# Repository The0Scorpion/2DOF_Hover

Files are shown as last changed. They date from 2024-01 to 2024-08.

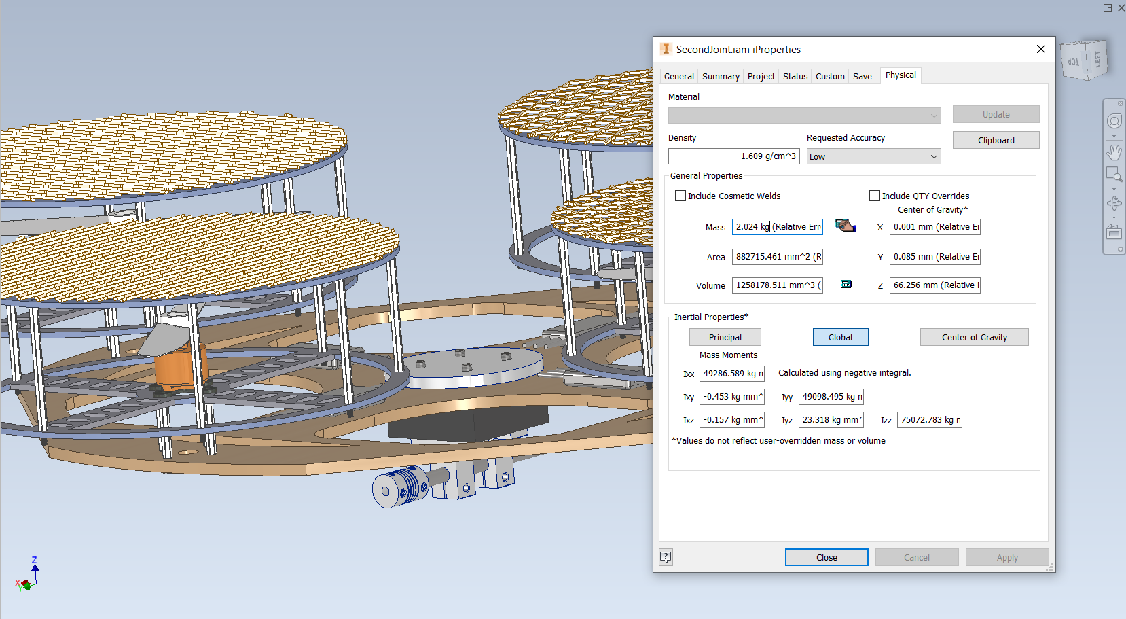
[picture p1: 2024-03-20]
CAD/Inertias/UpperJoint_Inertia_mass.PNG

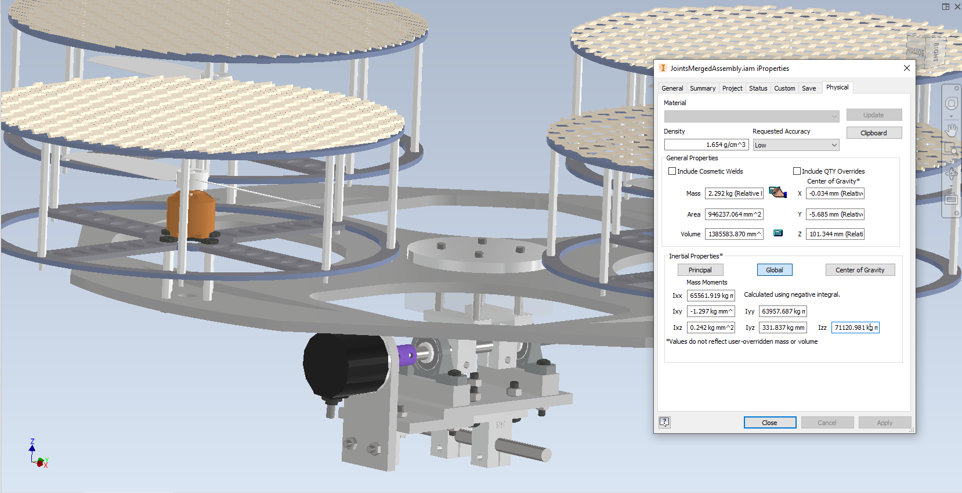
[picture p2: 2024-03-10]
Model/MotorEstimationModel/Inertias/InertiaLowerJoint.PNG

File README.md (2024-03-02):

# 2 DOF Hover
## Objective:
To create a smart lab that is designed to enhance the experince of students and tutors for control theory
## About
This is the full project files containing all of the diffrent source code files and CAD files to build a functional 2 DOF hover 
## Current Progress
We reached a functional state where the experment is working with AWS and Red.js app 
it features the ability to moniter and tune the hover in real-time

This is a Graduation Project Of an Mechatronics Engineering Team From ASU Faculty of engineering.

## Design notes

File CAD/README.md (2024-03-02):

# Mechanical Data
This section contains the CAD files for the mechaincal system
It was built using Autodesk Inventor, this is used to create the non linear model.

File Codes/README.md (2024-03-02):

# Source Codes
This section contains every software file that was used throught the development phase of the project.
### 2DOF_Full_Code
This is the full code of the project, it contains several modules that are working in parellal to maintain the operation of the drone.
### IOT_HubCode
this section is deprecated for the time being 
It will be used as a central hub to be an interface between all of the experiments and the IOT broker.
### IOTHUB_TESTONLY
This code is used for experminting.
Such as determining the paramters and delays.
### MotorResponseGrapher
Code used to determine the motor response curve to input and voltage
You can find the data in the /Data folder.

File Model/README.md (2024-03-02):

# available models for the system
## Non linear model 
The model created using the CAD files that closely relates the real model.
## Roll reduced model
Simplified model to design the controller on.

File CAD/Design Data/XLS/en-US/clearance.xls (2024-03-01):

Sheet: Ansi Unified Screw Threads
I | Sort Order -1
Fastener Type | Size | Shaft Diameters |  |  | Head Dimensions
 |  | Close | Normal | Loose | Diameter | Depth/Angle | Head Type
Flat Head Machine Screw (82) | #0 | 0.0635 | 0.07 | 0.073 | 0.119 | 82 | 2
Flat Head Machine Screw (82) | #1 | 0.076 | 0.081 | 0.089 | 0.146 | 82 | 2
Flat Head Machine Screw (82) | #2 | 0.089 | 0.096 | 0.1065 | 0.172 | 82 | 2
Flat Head Machine Screw (82) | #3 | 0.104 | 0.11 | 0.12 | 0.199 | 82 | 2
Flat Head Machine Screw (82) | #4 | 0.116 | 0.1285 | 0.136 | 0.225 | 82 | 2
Flat Head Machine Screw (82) | #5 | 0.1285 | 0.136 | 0.154 | 0.252 | 82 | 2
Flat Head Machine Screw (82) | #6 | 0.144 | 0.1495 | 0.1695 | 0.279 | 82 | 2
Flat Head Machine Screw (82) | #8 | 0.1695 | 0.177 | 0.1935 | 0.332 | 82 | 2
Flat Head Machine Screw (82) | #10 | 0.196 | 0.201 | 0.221 | 0.385 | 82 | 2
Flat Head Machine Screw (82) | #12 | 0.221 | 0.228 | 0.246 | 0.438 | 82 | 2
Flat Head Machine Screw (82) | 1/4 | 0.257 | 0.266 | 0.2812 | 0.507 | 82 | 2
Flat Head Machine Screw (82) | 5/16 | 0.323 | 0.332 | 0.3437 | 0.635 | 82 | 2
Flat Head Machine Screw (82) | 3/8 | 0.386 | 0.397 | 0.4062 | 0.762 | 82 | 2
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

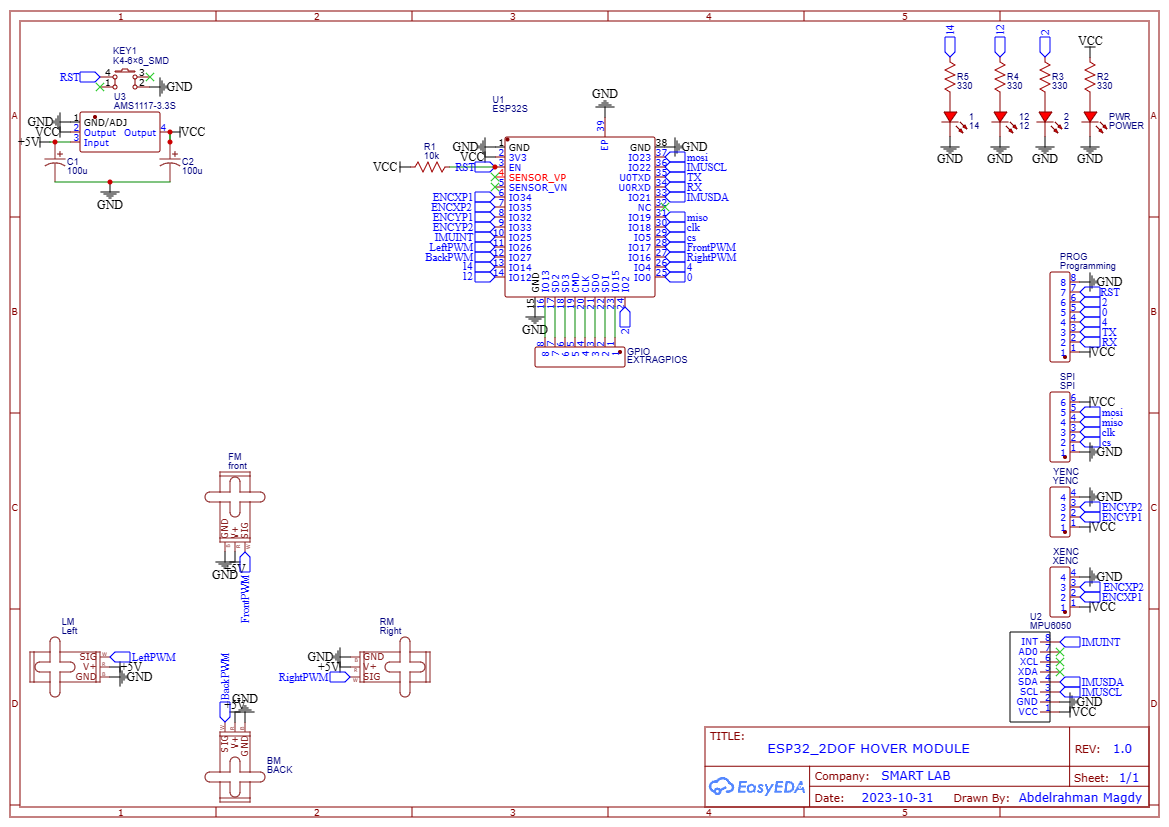
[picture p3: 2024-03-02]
Electric/Schematic_2DOF-Hover.png

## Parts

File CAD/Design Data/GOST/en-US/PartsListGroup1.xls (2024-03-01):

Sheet: Лист 1
Инв. № подл |  |  |  | Подп. и дата | Взам. инв. № | Инв. № дубл. |  |  | Подп. и дата
Формат | Зона | Поз. | Обозначение |  |  |  | Наименование |  |  |  |  |  | Кол. на исполнение
 |  |  |  |  |  |  |  |  |  |  |  | Лит.
 |  |  |  |  |  |  |  |  |  |  |  | Код
 |  |  |  |  |  |  |  | Изм. | Лист | № докум | Подпись |  | Дата
 |  |  |  |  |  |  |  | Разраб.
 |  |  |  |  |  |  |  | Пров.
 |  |  |  |  |  |  |  | Н.контр
 |  |  |  |  |  |  |  | Утв.
 |  |  |  |  |  |  |  |  |  |  |  |  |  | Копировал

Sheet: Лист 2
Инв. № подл |  |  |  | Подп. и дата | Взам. инв. № | Инв. № дубл. |  |  | Подп. и дата
Формат | Зона | Поз. | Обозначение |  |  |  | Наименование |  |  |  |  | Кол. на исполнение
 |  |  |  |  |  |  |  | Изм. | Лист | № докум. | Подп. | Дата
 |  |  |  |  |  |  |  |  |  |  |  |  | Копировал
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

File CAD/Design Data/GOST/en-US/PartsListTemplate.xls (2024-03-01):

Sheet: Лист 1
 | Формат | Зона |  | Поз. |  | Обозначение |  |  |  | Наименование |  |  |  | Кол. | Приме-чание
Подп. и дата
Инв. № дубл.
Взам. инв. №
Подп. и дата
 | Изм. |  | Лист |  | № докум |  | Подпись | Дата
Инв. № подл | Разраб. |  |  |  |  |  |  |  |  |  | Литера |  | Лист |  |  | Листов
 | Пров.
 | Н.контр
 | Утв.
 |  |  |  |  |  |  |  |  | Копировал |  |  | Формат А4

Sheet: Лист 2
 | Формат | Зона |  | Поз. |  | Обозначение |  |  |  | Наименование |  | Кол. | Приме-чание
Подп. и дата
Инв. № дубл.
Взам. инв. №
Подп. и дата
Инв. № подл
 | Изм. |  | Лист |  | № докум. |  | Подп. |  | Дата
 |  |  |  |  |  |  |  | Копировал |  |  | Формат А4
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

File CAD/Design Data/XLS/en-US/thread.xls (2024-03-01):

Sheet: Inch Tapping Threads
I Q X | Inch Tapping Threads |  | Sort Order - 5 |  | External |  |  |  |  |  |  | Internal
 |  |  |  |  |  | Major Dia |  | Pitch Dia |  | Minor Dia |  |  | Minor Dia |  | Pitch Dia |  | Major Dia |  | Tap Drill
Size | Size Suffix | Thread Designation | Custom Thread Designation | TPI | Class | Max | Min | Max | Min | Max | Min | Class | Min | Max | Min | Max | Min | Max | Basic
0.0600 |  | 0-48 | 0-48 | 48 | 2B | 0.0600 | 0.0540 | 0.0480 | 0.0435 | 0.0360 | 0.0330
0.0730 |  | 1-42 | 1-42 | 42 | 2B | 0.0750 | 0.0690 | 0.0620 | 0.0575 | 0.0490 | 0.0460
0.0860 |  | 2-32 | 2-32 | 32 | 2B | 0.0880 | 0.0820 | 0.0760 | 0.0710 | 0.0640 | 0.0600
0.0990 |  | 3-28 | 3-28 | 28 | 2B | 0.1010 | 0.0950 | 0.0880 | 0.0830 | 0.0750 | 0.0710
0.1120 |  | 4-24 | 4-24 | 24 | 2B | 0.1140 | 0.1080 | 0.1000 | 0.0950 | 0.0860 | 0.0820
0.1250 |  | 5-20 | 5-20 | 20 | 2B | 0.1300 | 0.1230 | 0.1120 | 0.1065 | 0.0940 | 0.0900
0.1380 |  | 6-20 | 6-20 | 20 | 2B | 0.1390 | 0.1320 | 0.1215 | 0.1155 | 0.1040 | 0.0990
0.1510 |  | 7-19 | 7-19 | 19 | 2B | 0.1540 | 0.1470 | 0.1345 | 0.1280 | 0.1150 | 0.1090
0.1640 |  | 8-18 | 8-18 | 18 | 2B | 0.1660 | 0.1590 | 0.1440 | 0.1375 | 0.1220 | 0.1160
0.1900 |  | 10-16 | 10-16 | 16 | 2B | 0.1890 | 0.1820 | 0.1650 | 0.1585 | 0.1410 | 0.1350
0.2160 |  | 12-14 | 12-14 | 14 | 2B | 0.2150 | 0.2080 | 0.1895 | 0.1825 | 0.1640 | 0.1570
0.2420 |  | 14-14 | 14-14 | 14 | 2B | 0.2410 | 0.2340 | 0.2130 | 0.2060 | 0.1850 | 0.1780
0.2500 |  | 1/4-14 | 1/4-14 | 14 | 2B | 0.2460 | 0.2370 | 0.2190 | 0.2110 | 0.1920 | 0.1850
0.3125 |  | 5/16-12 | 5/16-12 | 12 | 2B | 0.3150 | 0.3060 | 0.2795 | 0.2710 | 0.2440 | 0.2360
0.3750 |  | 3/8-12 | 3/8-12 | 12 | 2B | 0.3800 | 0.3710 | 0.3445 | 0.3350 | 0.3090 | 0.2990
0.4375 |  | 7/16-10 | 7/16-10 | 10 | 2B | 0.4400 | 0.4290 | 0.3995 | 0.3890 | 0.3590 | 0.3490
0.5000 |  | 1/2-10 | 1/2-10 | 10 | 2B | 0.5040 | 0.4930 | 0.4635 | 0.4530 | 0.4230 | 0.4130

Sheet: Metric Forming Screw Threads
M P X | Metric Forming Screw Threads |  | Sort Order - 6 |  | External |  |  |  |  |  |  | Internal
 |  |  |  |  |  | Major Dia |  | Pitch Dia |  | Minor Dia |  |  | Minor Dia |  | Pitch Dia |  | Major Dia |  | Tap Drill
Size | Size Suffix | Thread Designation | Custom Thread Designation | Pitch | Class | Max | Min | Max | Min | Max | Min | Class | Min | Max | Min | Max | Min | Max | Basic
1.5 |  | 1.5x0.5 | 1.5x0.5 | 0.5 | 6g | 1.520 | 1.380 | 1.215 | 1.110 | 0.910 | 0.840
1.5 |  | ST1.5x0.5 | ST1.5x0.5 | 0.5 | 6g | 1.520 | 1.380 | 1.215 | 1.110 | 0.910 | 0.840
1.9 |  | 1.9x0.6 | 1.9x0.6 | 0.6 | 6g | 1.900 | 1.760 | 1.570 | 1.465 | 1.240 | 1.170
1.9 |  | ST1.9x0.6 | ST1.9x0.6 | 0.6 | 6g | 1.900 | 1.760 | 1.570 | 1.465 | 1.240 | 1.170
2.2 |  | 2.2x0.8 | 2.2x0.8 | 0.8 | 6g | 2.240 | 2.100 | 1.935 | 1.810 | 1.630 | 1.520
2.2 |  | ST2.2x0.8 | ST2.2x0.8 | 0.8 | 6g | 2.240 | 2.100 | 1.935 | 1.810 | 1.630 | 1.520
2.6 |  | 2.6x0.9 | 2.6x0.9 | 0.9 | 6g | 2.570 | 2.430 | 2.235 | 2.115 | 1.900 | 1.800
2.6 |  | ST2.6x0.9 | ST2.6x0.9 | 0.9 | 6g | 2.570 | 2.430 | 2.235 | 2.115 | 1.900 | 1.800
2.9 |  | 2.9x1 | 2.9x1 | 1 | 6g | 2.900 | 2.760 | 2.540 | 2.420 | 2.180 | 2.080
2.9 |  | 2.9x1.1 | 2.9x1.1 | 1.1 | 6g | 2.900 | 2.760 | 2.540 | 2.420 | 2.180 | 2.080
2.9 |  | ST2.9x1.1 | ST2.9x1.1 | 1.1 | 6g | 2.900 | 2.760 | 2.540 | 2.420 | 2.180 | 2.080
2.9 |  | 2.9x1.3 | 2.9x1.3 | 1.3 | 6g | 2.900 | 2.720 | 2.540 | 2.355 | 1.890 | 1.700
2.9 |  | 2.9x1.4 | 2.9x1.4 | 1.4 | 6g | 2.900 | 2.720 | 2.340 | 2.175 | 1.780 | 1.630
3.3 |  | 3.3x1.3 | 3.3x1.3 | 1.3 | 6g | 3.300 | 3.120 | 2.795 | 2.665 | 2.290 | 2.210
3.3 |  | ST3.3x1.3 | ST3.3x1.3 | 1.3 | 6g | 3.300 | 3.120 | 2.795 | 2.665 | 2.290 | 2.210
3.5 |  | 3.5x1.3 | 3.5x1.3 | 1.3 | 6g | 3.530 | 3.350 | 3.085 | 2.930 | 2.640 | 2.510
3.5 |  | ST3.5x1.3 | ST3.5x1.3 | 1.3 | 6g | 3.530 | 3.350 | 3.085 | 2.930 | 2.640 | 2.510
3.5 |  | 3.5x1.6 | 3.5x1.6 | 1.6 | 6g | 3.530 | 3.350 | 2.920 | 2.755 | 2.310 | 2.160
3.5 |  | 3.5x3.2 | 3.5x3.2 | 3.2 | 6g | 3.530 | 3.310 | 2.800 | 2.600 | 2.070 | 1.890
3.9 |  | 3.9x1.3 | 3.9x1.3 | 1.3 | 6g | 3.910 | 3.730 | 3.415 | 3.250 | 2.920 | 2.770
3.9 |  | ST3.9x1.3 | ST3.9x1.3 | 1.3 | 6g | 3.910 | 3.730 | 3.415 | 3.250 | 2.920 | 2.770
3.9 |  | 3.9x1.6 | 3.9x1.6 | 1.6 | 6g | 3.910 | 3.730 | 3.300 | 3.135 | 2.690 | 2.540
3.9 |  | 3.9x3.2 | 3.9x3.2 | 3.2 | 6g | 3.910 | 3.690 | 3.180 | 2.980 | 2.450 | 2.270
4.2 |  | 4.2x1.4 | 4.2x1.4 | 1.4 | 6g | 4.220 | 4.040 | 3.660 | 3.495 | 3.100 | 2.950
4.2 |  | ST4.2x1.4 | ST4.2x1.4 | 1.4 | 6g | 4.220 | 4.040 | 3.660 | 3.495 | 3.100 | 2.950
4.2 |  | 4.2x1.6 | 4.2x1.6 | 1.6 | 6g | 4.220 | 4.040 | 3.610 | 3.445 | 3.000 | 2.850
4.2 |  | 4.2x3.2 | 4.2x3.2 | 3.2 | 6g | 4.220 | 4.000 | 3.380 | 3.180 | 2.540 | 2.360
4.8 |  | 4.8x1.6 | 4.8x1.6 | 1.6 | 6g | 4.800 | 4.620 | 4.190 | 4.025 | 3.580 | 3.430
4.8 |  | ST4.8x1.6 | ST4.8x1.6 | 1.6 | 6g | 4.800 | 4.620 | 4.190 | 4.025 | 3.580 | 3.430
4.8 |  | 4.8x1.8 | 4.8x1.8 | 1.8 | 6g | 4.800 | 4.620 | 4.065 | 3.885 | 3.330 | 3.150
4.8 |  | 4.8x3.2 | 4.8x3.2 | 3.2 | 6g | 4.800 | 4.580 | 3.960 | 3.760 | 3.120 | 2.940
5.5 |  | 5.5x1.8 | 5.5x1.8 | 1.8 | 6g | 5.460 | 5.280 | 4.815 | 4.635 | 4.170 | 3.990
5.5 |  | ST5.5x1.8 | ST5.5x1.8 | 1.8 | 6g | 5.460 | 5.280 | 4.815 | 4.635 | 4.170 | 3.990
6.3 |  | 6.3x1.8 | 6.3x1.8 | 1.8 | 6g | 6.250 | 6.030 | 5.565 | 5.365 | 4.880 | 4.700
6.3 |  | ST6.3x1.8 | ST6.3x1.8 | 1.8 | 6g | 6.250 | 6.030 | 5.565 | 5.365 | 4.880 | 4.700
8.0 |  | 8x2.1 | 8x2.1 | 2.1 | 6g | 8.000 | 7.780 | 7.100 | 6.885 | 6.200 | 5.990
8.0 |  | ST8x2.1 | ST8x2.1 | 2.1 | 6g | 8.000 | 7.780 | 7.100 | 6.885 | 6.200 | 5.990
9.5 |  | 9.5x2.1 | 9.5x2.1 | 2.1 | 6g | 9.650 | 9.430 | 8.750 | 8.510 | 7.850 | 7.590
9.5 |  | ST9.5x2.1 | ST9.5x2.1 | 2.1 | 6g | 9.650 | 9.430 | 8.750 | 8.510 | 7.850 | 7.590

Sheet: ISO Pipe Threads
M Q | ISO Pipe Threads |  | Sort Order - 9 |  | External |  |  |  |  |  |  | Internal
 |  |  |  |  |  | Major Dia |  | Pitch Dia |  | Minor Dia |  |  | Minor Dia |  | Pitch Dia |  | Major Dia |  | Tap Drill | Thread Depth | Thread Runouts
Size | Size Suffix | Thread Designation | Custom Thread Designation | TPI | Class | Max | Min | Max | Min | Max | Min | Class | Min | Max | Min | Max | Min | Max | Basic
7.723 |  | G7.723x0.907 | G 1/16 | 28 | A | 7.723 | 7.509 | 7.142 | 7.035 | 6.561 |  |  | 6.561 | 6.834 | 7.142 | 7.249 | 7.723 |  | 1.5875 | 15.446 | 4.5000
7.723 |  | G7.723x0.907 | G 1/16 | 28 | B | 7.723 | 7.509 | 7.142 | 6.928 | 6.561
9.728 |  | G9.728x0.907 | G 1/8 | 28 | A | 9.728 | 9.514 | 9.147 | 9.040 | 8.566 |  |  | 8.566 | 8.848 | 9.147 | 9.254 | 9.728 |  | 3.1750 | 19.456 | 4.5000
9.728 |  | G9.728x0.907 | G 1/8 | 28 | B | 9.728 | 9.514 | 9.147 | 8.933 | 8.566
13.157 |  | G13.157x1.337 | G 1/4 | 19 | A | 13.157 | 12.907 | 12.301 | 12.176 | 11.445 |  |  | 11.445 | 11.89 | 12.301 | 12.426 | 13.157 |  | 6.3500 | 26.314 | 6.5000
13.157 |  | G13.157x1.337 | G 1/4 | 19 | B | 13.157 | 12.907 | 12.301 | 12.051 | 11.445
16.662 |  | G16.662x1.337 | G 3/8 | 19 | A | 16.662 | 16.412 | 15.806 | 15.681 | 14.950 |  |  | 14.95 | 15.395 | 15.806 | 15.931 | 16.662 |  | 9.5250 | 33.324 | 6.5000
16.662 |  | G16.662x1.337 | G 3/8 | 19 | B | 16.662 | 16.412 | 15.806 | 15.556 | 14.950
20.955 |  | G20.955x1.814 | G 1/2 | 14 | A | 20.955 | 20.671 | 19.793 | 19.651 | 18.631 |  |  | 18.631 | 19.172 | 19.793 | 19.935 | 20.955 |  | 12.7000 | 41.910 | 8.5000
20.955 |  | G20.955x1.814 | G 1/2 | 14 | B | 20.955 | 20.671 | 19.793 | 19.509 | 18.631
22.911 |  | G22.911x1.814 | G 5/8 | 14 | A | 22.911 | 22.627 | 21.749 | 21.607 | 20.587 |  |  | 20.587 | 21.128 | 21.749 | 21.891 | 22.911 |  |  | 45.822 | 8.5000
22.911 |  | G22.911x1.814 | G 5/8 | 14 | B | 22.911 | 22.627 | 21.749 | 21.465 | 20.587
26.441 |  | G26.441x1.814 | G 3/4 | 14 | A | 26.441 | 26.157 | 25.279 | 25.137 | 24.117 |  |  | 24.117 | 24.658 | 25.279 | 25.421 | 26.441 |  | 15.8750 | 52.882 | 8.5000
26.441 |  | G26.441x1.814 | G 3/4 | 14 | B | 26.441 | 26.157 | 25.279 | 24.995 | 24.117
30.201 |  | G30.201x1.814 | G 7/8 | 14 | A | 30.201 | 29.917 | 29.039 | 28.897 | 27.877 |  |  | 27.877 | 28.418 | 29.039 | 29.181 | 30.201 |  | 22.2250 | 60.402 | 8.5000
30.201 |  | G30.201x1.814 | G 7/8 | 14 | B | 30.201 | 29.917 | 29.039 | 28.755 | 27.877
33.249 |  | G33.249x2.309 | G 1 | 11 | A | 33.249 | 32.889 | 31.770 | 31.590 | 30.291 |  |  | 30.291 | 30.931 | 31.77 | 31.95 | 33.249 |  | 25.4000 | 66.498 | 10.0000
33.249 |  | G33.249x2.309 | G 1 | 11 | B | 33.249 | 32.889 | 31.770 | 31.410 | 30.291
37.897 |  | G37.897x2.309 | G 1 1/8 | 11 | A | 37.897 | 37.537 | 36.418 | 36.238 | 34.939 |  |  | 34.939 | 35.579 | 36.418 | 36.598 | 37.897 |  | 28.5750 | 75.794 | 10.0000
37.897 |  | G37.897x2.309 | G 1 1/8 | 11 | B | 37.897 | 37.537 | 36.418 | 36.058 | 34.939
41.910 |  | G41.91x2.309 | G 1 1/4 | 11 | A | 41.910 | 41.550 | 40.431 | 40.251 | 38.952 |  |  | 38.952 | 39.592 | 40.431 | 40.611 | 41.910 |  | 31.7500 | 83.820 | 10.0000
41.910 |  | G41.91x2.309 | G 1 1/4 | 11 | B | 41.910 | 41.550 | 40.431 | 40.071 | 38.952
47.803 |  | G47.803x2.309 | G 1 1/2 | 11 | A | 47.803 | 47.443 | 46.324 | 46.144 | 44.845 |  |  | 44.845 | 45.485 | 46.324 | 46.504 | 47.803 |  | 38.1000 | 95.606 | 10.0000
47.803 |  | G47.803x2.309 | G 1 1/2 | 11 | B | 47.803 | 47.443 | 46.324 | 45.964 | 44.845
53.746 |  | G53.746x2.309 | G 1 3/4 | 11 | A | 53.746 | 53.386 | 52.267 | 52.087 | 50.788 |  |  | 50.788 | 51.428 | 52.267 | 52.447 | 53.746 |  | 44.4500 | 107.492 | 10.0000
53.746 |  | G53.746x2.309 | G 1 3/4 | 11 | B | 53.746 | 53.386 | 52.267 | 51.907 | 50.788
59.614 |  | G59.614x2.309 | G 2 | 11 | A | 59.614 | 59.254 | 58.135 | 57.955 | 56.656 |  |  | 56.656 | 57.296 | 58.135 | 58.315 | 59.614 |  | 50.8000 | 119.228 | 10.0000
59.614 |  | G59.614x2.309 | G 2 | 11 | B | 59.614 | 59.254 | 58.135 | 57.775 | 56.656
65.710 |  | G65.71x2.309 | G 2 1/4 | 11 | A | 65.710 | 65.276 | 64.231 | 64.014 | 62.752 |  |  | 62.752 | 63.392 | 64.231 | 64.448 | 65.710 |  | 57.1500 | 131.420 | 10.0000
65.710 |  | G65.71x2.309 | G 2 1/4 | 11 | B | 65.710 | 65.276 | 64.231 | 63.797 | 62.752
75.184 |  | G75.184x2.309 | G 2 1/2 | 11 | A | 75.184 | 74.750 | 73.705 | 73.488 | 72.226 |  |  | 72.226 | 72.866 | 73.705 | 73.922 | 75.184 |  |  | 150.368 | 10.0000
75.184 |  | G75.184x2.309 | G 2 1/2 | 11 | B | 75.184 | 74.750 | 73.705 | 73.271 | 72.226
81.534 |  | G81.534x2.309 | G 2 3/4 | 11 | A | 81.534 | 81.100 | 80.055 | 79.838 | 78.576 |  |  | 78.576 | 79.216 | 80.055 | 80.272 | 81.534 |  | 69.8500 | 163.068 | 10.0000
81.534 |  | G81.534x2.309 | G 2 3/4 | 11 | B | 81.534 | 81.100 | 80.055 | 79.621 | 78.576
87.884 |  | G87.884x2.309 | G 3 | 11 | A | 87.884 | 87.450 | 86.405 | 86.188 | 84.926 |  |  | 84.926 | 85.566 | 86.405 | 86.622 | 87.884 |  | 76.2000 | 175.768 | 10.0000
87.884 |  | G87.884x2.309 | G 3 | 11 | B | 87.884 | 87.450 | 86.405 | 85.971 | 84.926
100.330 |  | G100.33x2.309 | G 3 1/2 | 11 | A | 100.330 | 99.896 | 98.851 | 98.634 | 97.372 |  |  | 97.372 | 98.012 | 98.851 | 99.068 | 100.330 |  | 88.9000 | 200.660 | 10.0000
100.330 |  | G100.33x2.309 | G 3 1/2 | 11 | B | 100.330 | 99.896 | 98.851 | 98.417 | 97.372
113.030 |  | G113.03x2.309 | G 4 | 11 | A | 113.030 | 112.596 | 111.551 | 111.334 | 110.072 |  |  | 110.072 | 110.712 | 111.551 | 111.768 | 113.030 |  | 101.6000 | 226.060 | 10.0000
113.030 |  | G113.03x2.309 | G 4 | 11 | B | 113.030 | 112.596 | 111.551 | 111.117 | 110.072
125.730 |  | G125.73x2.309 | G 4 1/2 | 11 | A | 125.730 | 125.296 | 124.251 | 124.034 | 122.772 |  |  | 122.772 | 123.412 | 124.251 | 124.468 | 125.730 |  | 114.3000 | 251.460 | 10.0000
125.730 |  | G125.73x2.309 | G 4 1/2 | 11 | B | 125.730 | 125.296 | 124.251 | 123.817 | 122.772
138.430 |  | G138.43x2.309 | G 5 | 11 | A | 138.430 | 137.996 | 136.951 | 136.734 | 135.472 |  |  | 135.472 | 136.112 | 136.951 | 137.168 | 138.430 |  | 127.0000 | 276.860 | 10.0000
138.430 |  | G138.43x2.309 | G 5 | 11 | B | 138.430 | 137.996 | 136.951 | 136.517 | 135.472
151.130 |  | G151.13x2.309 | G 5 1/2 | 11 | A | 151.130 | 150.696 | 149.651 | 149.434 | 148.172 |  |  | 148.172 | 148.812 | 149.651 | 149.868 | 151.130 |  | 139.7000 | 302.260 | 10.0000
151.130 |  | G151.13x2.309 | G 5 1/2 | 11 | B | 151.130 | 150.696 | 149.651 | 149.217 | 148.172
163.830 |  | G163.83x2.309 | G 6 | 11 | A | 163.830 | 163.396 | 162.351 | 162.134 | 160.872 |  |  | 160.872 | 161.512 | 162.351 | 162.568 | 163.830 |  | 152.4000 | 327.660 | 10.0000
163.830 |  | G163.83x2.309 | G 6 | 11 | B | 163.830 | 163.396 | 162.351 | 161.917 | 160.872

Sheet: JIS Pipe Threads
M Q | JIS Pipe Threads |  | Sort Order -12 |  | External |  |  |  |  |  |  | Internal
 |  |  |  |  |  | Major Dia |  | Pitch Dia |  | Minor Dia |  |  | Minor Dia |  | Pitch Dia |  | Major Dia |  | Tap Drill | Thread Depth | Thread Runouts
Size | Size Suffix | Thread Designation | Custom Thread Designation | TPI | Class | Max | Min | Max | Min | Max | Min | Class | Min | Max | Min | Max | Min | Max | Basic |  | Basic
7.723 |  | G7.723x0.907 | G 1/16 | 28 | A | 7.723 | 7.509 | 7.142 | 7.035 | 6.561 |  |  | 6.561 | 6.834 | 7.142 | 7.249 | 7.723 |  | 1.5875 | 15.446 | 4.5000
7.723 |  | G7.723x0.907 | G 1/16 | 28 | B | 7.723 | 7.509 | 7.142 | 6.928 | 6.561
9.728 |  | G9.728x0.907 | G 1/8 | 28 | A | 9.728 | 9.514 | 9.147 | 9.040 | 8.566 |  |  | 8.566 | 8.848 | 9.147 | 9.254 | 9.728 |  | 3.1750 | 19.456 | 4.5000
9.728 |  | G9.728x0.907 | G 1/8 | 28 | B | 9.728 | 9.514 | 9.147 | 8.933 | 8.566
13.157 |  | G13.157x1.337 | G 1/4 | 19 | A | 13.157 | 12.907 | 12.301 | 12.176 | 11.445 |  |  | 11.445 | 11.89 | 12.301 | 12.426 | 13.157 |  | 6.3500 | 26.314 | 6.5000
13.157 |  | G13.157x1.337 | G 1/4 | 19 | B | 13.157 | 12.907 | 12.301 | 12.051 | 11.445
16.662 |  | G16.662x1.337 | G 3/8 | 19 | A | 16.662 | 16.412 | 15.806 | 15.681 | 14.950 |  |  | 14.95 | 15.395 | 15.806 | 15.931 | 16.662 |  | 9.5250 | 33.324 | 6.5000
16.662 |  | G16.662x1.337 | G 3/8 | 19 | B | 16.662 | 16.412 | 15.806 | 15.556 | 14.950
20.955 |  | G20.955x1.814 | G 1/2 | 14 | A | 20.955 | 20.671 | 19.793 | 19.651 | 18.631 |  |  | 18.631 | 19.172 | 19.793 | 19.935 | 20.955 |  | 12.7000 | 41.910 | 8.5000
20.955 |  | G20.955x1.814 | G 1/2 | 14 | B | 20.955 | 20.671 | 19.793 | 19.509 | 18.631
22.911 |  | G22.911x1.814 | G 5/8 | 14 | A | 22.911 | 22.627 | 21.749 | 21.607 | 20.587 |  |  | 20.587 | 21.128 | 21.749 | 21.891 | 22.911 |  |  | 45.822 | 8.5000
22.911 |  | G22.911x1.814 | G 5/8 | 14 | B | 22.911 | 22.627 | 21.749 | 21.465 | 20.587
26.441 |  | G26.441x1.814 | G 3/4 | 14 | A | 26.441 | 26.157 | 25.279 | 25.137 | 24.117 |  |  | 24.117 | 24.658 | 25.279 | 25.421 | 26.441 |  | 15.8750 | 52.882 | 8.5000
26.441 |  | G26.441x1.814 | G 3/4 | 14 | B | 26.441 | 26.157 | 25.279 | 24.995 | 24.117
30.201 |  | G30.201x1.814 | G 7/8 | 14 | A | 30.201 | 29.917 | 29.039 | 28.897 | 27.877 |  |  | 27.877 | 28.418 | 29.039 | 29.181 | 30.201 |  | 22.2250 | 60.402 | 8.8000
30.201 |  | G30.201x1.814 | G 7/8 | 14 | B | 30.201 | 29.917 | 29.039 | 28.755 | 27.877
33.249 |  | G33.249x2.309 | G 1 | 11 | A | 33.249 | 32.889 | 31.770 | 31.590 | 30.291 |  |  | 30.291 | 30.931 | 31.77 | 31.95 | 33.249 |  | 25.4000 | 66.498 | 10.0000
33.249 |  | G33.249x2.309 | G 1 | 11 | B | 33.249 | 32.889 | 31.770 | 31.410 | 30.291
37.897 |  | G37.897x2.309 | G 1 1/8 | 11 | A | 37.897 | 37.537 | 36.418 | 36.238 | 34.939 |  |  | 34.939 | 35.579 | 36.418 | 36.598 | 37.897 |  | 28.5750 | 75.794 | 10.0000
37.897 |  | G37.897x2.309 | G 1 1/8 | 11 | B | 37.897 | 37.537 | 36.418 | 36.058 | 34.939
41.910 |  | G41.91x2.309 | G 1 1/4 | 11 | A | 41.910 | 41.550 | 40.431 | 40.251 | 38.952 |  |  | 38.952 | 39.592 | 40.431 | 40.611 | 41.910 |  | 31.7500 | 83.820 | 10.0000
41.910 |  | G41.91x2.309 | G 1 1/4 | 11 | B | 41.910 | 41.550 | 40.431 | 40.071 | 38.952
47.803 |  | G47.803x2.309 | G 1 1/2 | 11 | A | 47.803 | 47.443 | 46.324 | 46.144 | 44.845 |  |  | 44.845 | 45.485 | 46.324 | 46.504 | 47.803 |  | 38.1000 | 95.606 | 10.0000
47.803 |  | G47.803x2.309 | G 1 1/2 | 11 | B | 47.803 | 47.443 | 46.324 | 45.964 | 44.845
53.746 |  | G53.746x2.309 | G 1 3/4 | 11 | A | 53.746 | 53.386 | 52.267 | 52.087 | 50.788 |  |  | 50.788 | 51.428 | 52.267 | 52.447 | 53.746 |  | 44.4500 | 107.492 | 10.0000
53.746 |  | G53.746x2.309 | G 1 3/4 | 11 | B | 53.746 | 53.386 | 52.267 | 51.907 | 50.788
59.614 |  | G59.614x2.309 | G 2 | 11 | A | 59.614 | 59.254 | 58.135 | 57.955 | 56.656 |  |  | 56.656 | 57.296 | 58.135 | 58.315 | 59.614 |  | 50.8000 | 119.228 | 10.0000
59.614 |  | G59.614x2.309 | G 2 | 11 | B | 59.614 | 59.254 | 58.135 | 57.775 | 56.656
65.710 |  | G65.71x2.309 | G 2 1/4 | 11 | A | 65.710 | 65.276 | 64.231 | 64.014 | 62.752 |  |  | 62.752 | 63.392 | 64.231 | 64.448 | 65.710 |  | 57.1500 | 131.420 | 10.0000
65.710 |  | G65.71x2.309 | G 2 1/4 | 11 | B | 65.710 | 65.276 | 64.231 | 63.797 | 62.752
75.184 |  | G75.184x2.309 | G 2 1/2 | 11 | A | 75.184 | 74.750 | 73.705 | 73.488 | 72.226 |  |  | 72.226 | 72.866 | 73.705 | 73.922 | 75.184 |  |  | 150.368 | 10.0000
75.184 |  | G75.184x2.309 | G 2 1/2 | 11 | B | 75.184 | 74.750 | 73.705 | 73.271 | 72.226
81.534 |  | G81.534x2.309 | G 2 3/4 | 11 | A | 81.534 | 81.100 | 80.055 | 79.838 | 78.576 |  |  | 78.576 | 79.216 | 80.055 | 80.272 | 81.534 |  | 69.8500 | 163.068 | 10.0000
81.534 |  | G81.534x2.309 | G 2 3/4 | 11 | B | 81.534 | 81.100 | 80.055 | 79.621 | 78.576
87.884 |  | G87.884x2.309 | G 3 | 11 | A | 87.884 | 87.450 | 86.405 | 86.188 | 84.926 |  |  | 84.926 | 85.566 | 86.405 | 86.622 | 87.884 |  | 76.2000 | 175.768 | 10.0000
87.884 |  | G87.884x2.309 | G 3 | 11 | B | 87.884 | 87.450 | 86.405 | 85.971 | 84.926
100.330 |  | G100.33x2.309 | G 3 1/2 | 11 | A | 100.330 | 99.896 | 98.851 | 98.634 | 97.372 |  |  | 97.372 | 98.012 | 98.851 | 99.068 | 100.330 |  | 88.9000 | 200.660 | 10.0000
100.330 |  | G100.33x2.309 | G 3 1/2 | 11 | B | 100.330 | 99.896 | 98.851 | 98.417 | 97.372
113.030 |  | G113.03x2.309 | G 4 | 11 | A | 113.030 | 112.596 | 111.551 | 111.334 | 110.072 |  |  | 110.072 | 110.712 | 111.551 | 111.768 | 113.030 |  | 101.6000 | 226.060 | 10.0000
113.030 |  | G113.03x2.309 | G 4 | 11 | B | 113.030 | 112.596 | 111.551 | 111.117 | 110.072
125.730 |  | G125.73x2.309 | G 4 1/2 | 11 | A | 125.730 | 125.296 | 124.251 | 124.034 | 122.772 |  |  | 122.772 | 123.412 | 124.251 | 124.468 | 125.730 |  | 114.3000 | 251.460 | 10.0000
125.730 |  | G125.73x2.309 | G 4 1/2 | 11 | B | 125.730 | 125.296 | 124.251 | 123.817 | 122.772
138.430 |  | G138.43x2.309 | G 5 | 11 | A | 138.430 | 137.996 | 136.951 | 136.734 | 135.472 |  |  | 135.472 | 136.112 | 136.951 | 137.168 | 138.430 |  | 127.0000 | 276.860 | 10.0000
138.430 |  | G138.43x2.309 | G 5 | 11 | B | 138.430 | 137.996 | 136.951 | 136.517 | 135.472
151.130 |  | G151.13x2.309 | G 5 1/2 | 11 | A | 151.130 | 150.696 | 149.651 | 149.434 | 148.172 |  |  | 148.172 | 148.812 | 149.651 | 149.868 | 151.130 |  | 139.7000 | 302.260 | 10.0000
151.130 |  | G151.13x2.309 | G 5 1/2 | 11 | B | 151.130 | 150.696 | 149.651 | 149.217 | 148.172
163.830 |  | G163.83x2.309 | G 6 | 11 | A | 163.830 | 163.396 | 162.351 | 162.134 | 160.872 |  |  | 160.872 | 161.512 | 162.351 | 162.568 | 163.830 |  | 152.4000 | 327.660 | 10.0000
163.830 |  | G163.83x2.309 | G 6 | 11 | B | 163.830 | 163.396 | 162.351 | 161.917 | 160.872

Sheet: DIN Pipe Threads
M Q | DIN Pipe Threads |  | Sort Order - 18 |  | External |  |  |  |  |  |  | Internal
 |  |  |  |  |  | Major Dia |  | Pitch Dia |  | Minor Dia |  |  | Minor Dia |  | Pitch Dia |  | Major Dia |  | Tap Drill | Thread Depth | Thread Runouts
Size | Size Suffix | Thread Designation | Custom Thread Designation | TPI | Class | Max | Min | Max | Min | Max | Min | Class | Min | Max | Min | Max | Min | Max | Basic
7.723 |  | G7.723x0.907 | G 1/16 | 28 | A | 7.723 | 7.509 | 7.142 | 7.035 | 6.561 |  |  | 6.561 | 6.834 | 7.142 | 7.249 | 7.723 |  | 1.5875 | 15.446 | 4.5000
7.723 |  | G7.723x0.907 | G 1/16 | 28 | B | 7.723 | 7.509 | 7.142 | 6.928 | 6.561
9.728 |  | G9.728x0.907 | G 1/8 | 28 | A | 9.728 | 9.514 | 9.147 | 9.040 | 8.566 |  |  | 8.566 | 8.848 | 9.147 | 9.254 | 9.728 |  | 3.1750 | 19.456 | 4.5000
9.728 |  | G9.728x0.907 | G 1/8 | 28 | B | 9.728 | 9.514 | 9.147 | 8.933 | 8.566
13.157 |  | G13.157x1.337 | G 1/4 | 19 | A | 13.157 | 12.907 | 12.301 | 12.176 | 11.445 |  |  | 11.445 | 11.89 | 12.301 | 12.426 | 13.157 |  | 6.3500 | 26.314 | 6.5000
13.157 |  | G13.157x1.337 | G 1/4 | 19 | B | 13.157 | 12.907 | 12.301 | 12.051 | 11.445
16.662 |  | G16.662x1.337 | G 3/8 | 19 | A | 16.662 | 16.412 | 15.806 | 15.681 | 14.950 |  |  | 14.95 | 15.395 | 15.806 | 15.931 | 16.662 |  | 9.5250 | 33.324 | 6.5000
16.662 |  | G16.662x1.337 | G 3/8 | 19 | B | 16.662 | 16.412 | 15.806 | 15.556 | 14.950
20.955 |  | G20.955x1.814 | G 1/2 | 14 | A | 20.955 | 20.671 | 19.793 | 19.651 | 18.631 |  |  | 18.631 | 19.172 | 19.793 | 19.935 | 20.955 |  | 12.7000 | 41.910 | 8.5000
20.955 |  | G20.955x1.814 | G 1/2 | 14 | B | 20.955 | 20.671 | 19.793 | 19.509 | 18.631
22.911 |  | G22.911x1.814 | G 5/8 | 14 | A | 22.911 | 22.627 | 21.749 | 21.607 | 20.587 |  |  | 20.587 | 21.128 | 21.749 | 21.891 | 22.911 |  |  | 45.822 | 8.5000
22.911 |  | G22.911x1.814 | G 5/8 | 14 | B | 22.911 | 22.627 | 21.749 | 21.465 | 20.587
26.441 |  | G26.441x1.814 | G 3/4 | 14 | A | 26.441 | 26.157 | 25.279 | 25.137 | 24.117 |  |  | 24.117 | 24.658 | 25.279 | 25.421 | 26.441 |  | 15.8750 | 52.882 | 8.5000
26.441 |  | G26.441x1.814 | G 3/4 | 14 | B | 26.441 | 26.157 | 25.279 | 24.995 | 24.117
30.201 |  | G30.201x1.814 | G 7/8 | 14 | A | 30.201 | 29.917 | 29.039 | 28.897 | 27.877 |  |  | 27.877 | 28.418 | 29.039 | 29.181 | 30.201 |  | 22.2250 | 60.402 | 8.5000
30.201 |  | G30.201x1.814 | G 7/8 | 14 | B | 30.201 | 29.917 | 29.039 | 28.755 | 27.877
33.249 |  | G33.249x2.309 | G 1 | 11 | A | 33.249 | 32.889 | 31.770 | 31.590 | 30.291 |  |  | 30.291 | 30.931 | 31.77 | 31.95 | 33.249 |  | 25.4000 | 66.498 | 10.5000
33.249 |  | G33.249x2.309 | G 1 | 11 | B | 33.249 | 32.889 | 31.770 | 31.410 | 30.291
37.897 |  | G37.897x2.309 | G 1 1/8 | 11 | A | 37.897 | 37.537 | 36.418 | 36.238 | 34.939 |  |  | 34.939 | 35.579 | 36.418 | 36.598 | 37.897 |  | 28.5750 | 75.794 | 10.5000
37.897 |  | G37.897x2.309 | G 1 1/8 | 11 | B | 37.897 | 37.537 | 36.418 | 36.058 | 34.939
41.910 |  | G41.91x2.309 | G 1 1/4 | 11 | A | 41.910 | 41.550 | 40.431 | 40.251 | 38.952 |  |  | 38.952 | 39.592 | 40.431 | 40.611 | 41.910 |  | 31.7500 | 83.820 | 10.5000
41.910 |  | G41.91x2.309 | G 1 1/4 | 11 | B | 41.910 | 41.550 | 40.431 | 40.071 | 38.952
47.803 |  | G47.803x2.309 | G 1 1/2 | 11 | A | 47.803 | 47.443 | 46.324 | 46.144 | 44.845 |  |  | 44.845 | 45.485 | 46.324 | 46.504 | 47.803 |  | 38.1000 | 95.606 | 10.5000
47.803 |  | G47.803x2.309 | G 1 1/2 | 11 | B | 47.803 | 47.443 | 46.324 | 45.964 | 44.845
53.746 |  | G53.746x2.309 | G 1 3/4 | 11 | A | 53.746 | 53.386 | 52.267 | 52.087 | 50.788 |  |  | 50.788 | 51.428 | 52.267 | 52.447 | 53.746 |  | 44.4500 | 107.492 | 10.5000
53.746 |  | G53.746x2.309 | G 1 3/4 | 11 | B | 53.746 | 53.386 | 52.267 | 51.907 | 50.788
59.614 |  | G59.614x2.309 | G 2 | 11 | A | 59.614 | 59.254 | 58.135 | 57.955 | 56.656 |  |  | 56.656 | 57.296 | 58.135 | 58.315 | 59.614 |  | 50.8000 | 119.228 | 10.5000
59.614 |  | G59.614x2.309 | G 2 | 11 | B | 59.614 | 59.254 | 58.135 | 57.775 | 56.656
65.710 |  | G65.71x2.309 | G 2 1/4 | 11 | A | 65.710 | 65.276 | 64.231 | 64.014 | 62.752 |  |  | 62.752 | 63.392 | 64.231 | 64.448 | 65.710 |  | 57.1500 | 131.420 | 10.5000
65.710 |  | G65.71x2.309 | G 2 1/4 | 11 | B | 65.710 | 65.276 | 64.231 | 63.797 | 62.752
75.184 |  | G75.184x2.309 | G 2 1/2 | 11 | A | 75.184 | 74.750 | 73.705 | 73.488 | 72.226 |  |  | 72.226 | 72.866 | 73.705 | 73.922 | 75.184 |  |  | 150.368 | 10.5000
75.184 |  | G75.184x2.309 | G 2 1/2 | 11 | B | 75.184 | 74.750 | 73.705 | 73.271 | 72.226
81.534 |  | G81.534x2.309 | G 2 3/4 | 11 | A | 81.534 | 81.100 | 80.055 | 79.838 | 78.576 |  |  | 78.576 | 79.216 | 80.055 | 80.272 | 81.534 |  | 69.8500 | 163.068 | 10.5000
81.534 |  | G81.534x2.309 | G 2 3/4 | 11 | B | 81.534 | 81.100 | 80.055 | 79.621 | 78.576
87.884 |  | G87.884x2.309 | G 3 | 11 | A | 87.884 | 87.450 | 86.405 | 86.188 | 84.926 |  |  | 84.926 | 85.566 | 86.405 | 86.622 | 87.884 |  | 76.2000 | 175.768 | 10.5000
87.884 |  | G87.884x2.309 | G 3 | 11 | B | 87.884 | 87.450 | 86.405 | 85.971 | 84.926
100.330 |  | G100.33x2.309 | G 3 1/2 | 11 | A | 100.330 | 99.896 | 98.851 | 98.634 | 97.372 |  |  | 97.372 | 98.012 | 98.851 | 99.068 | 100.330 |  | 88.9000 | 200.660 | 10.5000
100.330 |  | G100.33x2.309 | G 3 1/2 | 11 | B | 100.330 | 99.896 | 98.851 | 98.417 | 97.372
113.030 |  | G113.03x2.309 | G 4 | 11 | A | 113.030 | 112.596 | 111.551 | 111.334 | 110.072 |  |  | 110.072 | 110.712 | 111.551 | 111.768 | 113.030 |  | 101.6000 | 226.060 | 10.5000
113.030 |  | G113.03x2.309 | G 4 | 11 | B | 113.030 | 112.596 | 111.551 | 111.117 | 110.072
125.730 |  | G125.73x2.309 | G 4 1/2 | 11 | A | 125.730 | 125.296 | 124.251 | 124.034 | 122.772 |  |  | 122.772 | 123.412 | 124.251 | 124.468 | 125.730 |  | 114.3000 | 251.460 | 10.5000
125.730 |  | G125.73x2.309 | G 4 1/2 | 11 | B | 125.730 | 125.296 | 124.251 | 123.817 | 122.772
138.430 |  | G138.43x2.309 | G 5 | 11 | A | 138.430 | 137.996 | 136.951 | 136.734 | 135.472 |  |  | 135.472 | 136.112 | 136.951 | 137.168 | 138.430 |  | 127.0000 | 276.860 | 10.5000
138.430 |  | G138.43x2.309 | G 5 | 11 | B | 138.430 | 137.996 | 136.951 | 136.517 | 135.472
151.130 |  | G151.13x2.309 | G 5 1/2 | 11 | A | 151.130 | 150.696 | 149.651 | 149.434 | 148.172 |  |  | 148.172 | 148.812 | 149.651 | 149.868 | 151.130 |  | 139.7000 | 302.260 | 10.5000
151.130 |  | G151.13x2.309 | G 5 1/2 | 11 | B | 151.130 | 150.696 | 149.651 | 149.217 | 148.172
163.830 |  | G163.83x2.309 | G 6 | 11 | A | 163.830 | 163.396 | 162.351 | 162.134 | 160.872 |  |  | 160.872 | 161.512 | 162.351 | 162.568 | 163.830 |  | 152.4000 | 327.660 | 10.5000
163.830 |  | G163.83x2.309 | G 6 | 11 | B | 163.830 | 163.396 | 162.351 | 161.917 | 160.872

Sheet: BSP Pipe Threads
M Q | BSP Pipe Threads |  | Sort Order - 19 |  | External |  |  |  |  |  |  | Internal
 |  |  |  |  |  | Major Dia |  | Pitch Dia |  | Minor Dia |  |  | Minor Dia |  | Pitch Dia |  | Major Dia |  | Tap Drill | Thread Depth | Thread Runouts
Size | Size Suffix | Thread Designation | Custom Thread Designation | TPI | Class | Max | Min | Max | Min | Max | Min | Class | Min | Max | Min | Max | Min | Max | Basic |  | Basic
1/16 |  | G 1/16-28 | G 1/16-28 | 28 | A | 7.723 | 7.509 | 7.142 | 7.035 | 6.561 |  |  | 6.561 | 6.834 | 7.142 | 7.249 | 7.723 |  | 6.6000 | 15.4460 | 4.5000
1/16 |  | G 1/16-28 | G 1/16-28 | 28 | B | 7.723 | 7.509 | 7.142 | 7.035 | 6.561
1/8 |  | G 1/8-28 | G 1/8-28 | 28 | A | 9.728 | 9.514 | 9.147 | 9.040 | 8.566 |  |  | 8.566 | 8.848 | 9.147 | 9.254 | 9.728 |  | 8.7300 | 19.4560 | 4.5000
1/8 |  | G 1/8-28 | G 1/8-28 | 28 | B | 9.728 | 9.514 | 9.147 | 9.040 | 8.566
1/4 |  | G 1/4-19 | G 1/4-19 | 19 | A | 13.157 | 12.907 | 12.301 | 12.176 | 11.445 |  |  | 11.445 | 11.89 | 12.301 | 12.426 | 13.157 |  | 11.8000 | 26.3140 | 6.5000
1/4 |  | G 1/4-19 | G 1/4-19 | 19 | B | 13.157 | 12.907 | 12.301 | 12.176 | 11.445
3/8 |  | G 3/8-19 | G 3/8-19 | 19 | A | 16.662 | 16.412 | 15.806 | 15.681 | 14.950 |  |  | 14.95 | 15.395 | 15.806 | 15.931 | 16.662 |  | 15.2500 | 33.3240 | 6.5000
3/8 |  | G 3/8-19 | G 3/8-19 | 19 | B | 16.662 | 16.412 | 15.806 | 15.681 | 14.950
1/2 |  | G 1/2-14 | G 1/2-14 | 14 | A | 20.955 | 20.671 | 19.793 | 19.651 | 18.631 |  |  | 18.631 | 19.172 | 19.793 | 19.935 | 20.955 |  | 19.0500 | 41.9100 | 8.5000
1/2 |  | G 1/2-14 | G 1/2-14 | 14 | B | 20.955 | 20.671 | 19.793 | 19.651 | 18.631
5/8 |  | G 5/8-14 | G 5/8-14 | 14 | A | 22.911 | 22.627 | 21.749 | 21.607 | 20.587 |  |  | 20.587 | 21.128 | 21.749 | 21.891 | 22.911 |  | 21.0000 | 45.8220 | 8.5000
5/8 |  | G 5/8-14 | G 5/8-14 | 14 | B | 22.911 | 22.627 | 21.749 | 21.607 | 20.587
3/4 |  | G 3/4-14 | G 3/4-14 | 14 | A | 26.441 | 26.157 | 25.279 | 25.137 | 24.117 |  |  | 24.117 | 24.658 | 25.279 | 25.421 | 26.441 |  | 24.5000 | 52.8820 | 8.5000
3/4 |  | G 3/4-14 | G 3/4-14 | 14 | B | 26.441 | 26.157 | 25.279 | 25.137 | 24.117
7/8 |  | G 7/8-14 | G 7/8-14 | 14 | A | 30.201 | 29.917 | 29.039 | 28.897 | 27.877 |  |  | 27.877 | 28.418 | 29.039 | 29.181 | 30.201 |  | 28.2500 | 60.4020 | 8.5000
7/8 |  | G 7/8-14 | G 7/8-14 | 14 | B | 30.201 | 29.917 | 29.039 | 28.897 | 27.877
1 |  | G 1-11 | G 1-11 | 11 | A | 33.249 | 32.889 | 31.770 | 31.590 | 30.291 |  |  | 30.291 | 30.931 | 31.77 | 31.95 | 33.249 |  | 30.7500 | 66.4980 | 10.0000
1 |  | G 1-11 | G 1-11 | 11 | B | 33.249 | 32.889 | 31.770 | 31.590 | 30.291
1 1/4 |  | G 1 1/4-11 | G 1 1/4-11 | 11 | A | 41.910 | 41.550 | 40.431 | 40.251 | 38.952 |  |  | 38.952 | 39.592 | 40.431 | 40.611 | 41.910 |  | 39.5000 | 83.8200 | 10.0000
1 1/4 |  | G 1 1/4-11 | G 1 1/4-11 | 11 | B | 41.910 | 41.550 | 40.431 | 40.251 | 38.952
1 1/2 |  | G 1 1/2-11 | G 1 1/2-11 | 11 | A | 47.803 | 47.443 | 46.324 | 46.144 | 44.845 |  |  | 44.845 | 45.485 | 46.324 | 46.504 | 47.803 |  | 45.5000 | 95.6060 | 10.0000
1 1/2 |  | G 1 1/2-11 | G 1 1/2-11 | 11 | B | 47.803 | 47.443 | 46.324 | 46.144 | 44.845
1 3/4 |  | G 1 3/4-11 | G 1 3/4-11 | 11 | A | 53.746 | 53.386 | 52.267 | 52.087 | 50.788 |  |  | 50.788 | 51.428 | 52.267 | 52.447 | 53.746 |  | 51.0000 | 107.4920 | 10.0000
1 3/4 |  | G 1 3/4-11 | G 1 3/4-11 | 11 | B | 53.746 | 53.386 | 52.267 | 52.087 | 50.788
2 |  | G 2-11 | G 2-11 | 11 | A | 59.614 | 59.254 | 58.135 | 57.955 | 56.656 |  |  | 56.656 | 57.296 | 58.135 | 58.315 | 59.614 |  | 57.0000 | 119.2280 | 10.0000
2 |  | G 2-11 | G 2-11 | 11 | B | 59.614 | 59.254 | 58.135 | 57.955 | 56.656
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

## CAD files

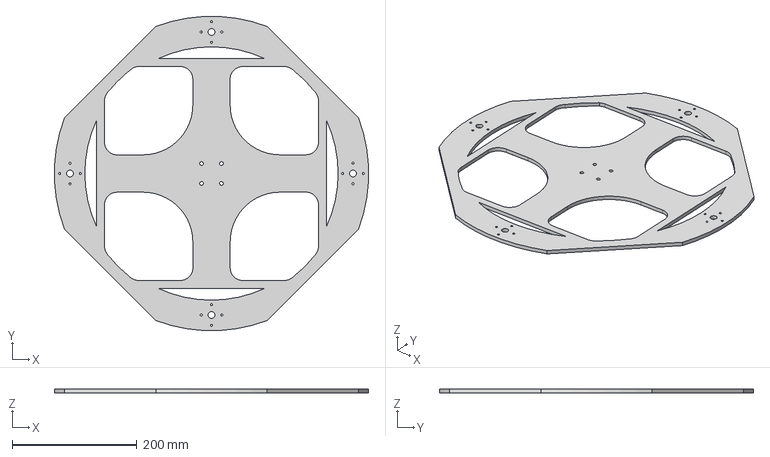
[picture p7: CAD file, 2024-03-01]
Model/Non Linear Model/Assembly231015Kerangka Bawah 1_ipt_5129a7e7.STEP
504.3 x 504.3 x 6.00 mm

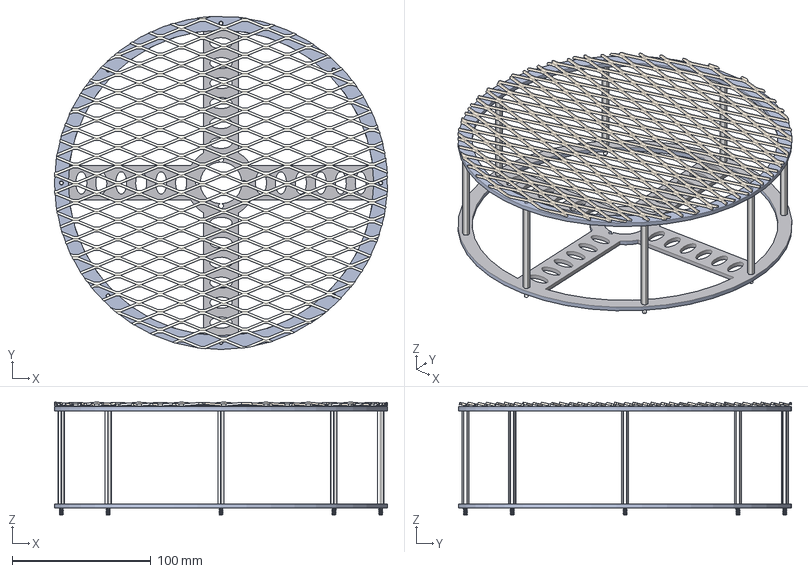
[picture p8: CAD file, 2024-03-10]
CAD/Workspaces/Workspace/guard.step
240.0 x 239.8 x 81.3 mm
XS42.STEP
spacers for prop:1
spacers for prop:2
spacers for prop:3
spacers for prop:4
spacers for prop:5
spacers for prop:6
spacers for prop:7
spacers for prop:8
Standoff M3 M-M H 45mm:1
Standoff M3 M-M H 45mm:2
Standoff M3 M-M H 45mm:3
Standoff M3 M-M H 45mm:4

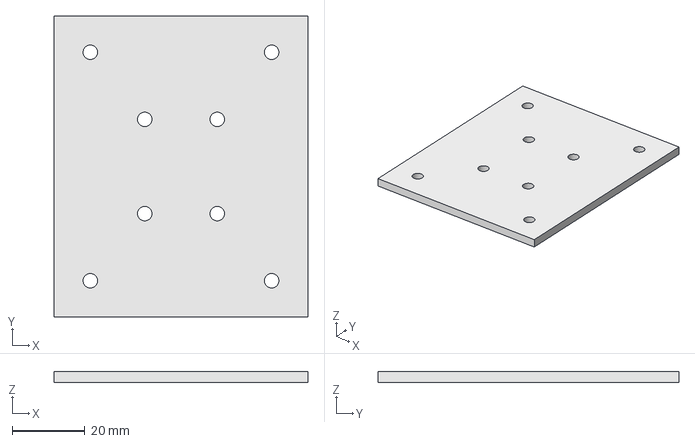
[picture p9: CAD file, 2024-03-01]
Model/Non Linear Model/BaseC_8_ipt_c1370e84.STEP
70.0 x 83.0 x 3.00 mm

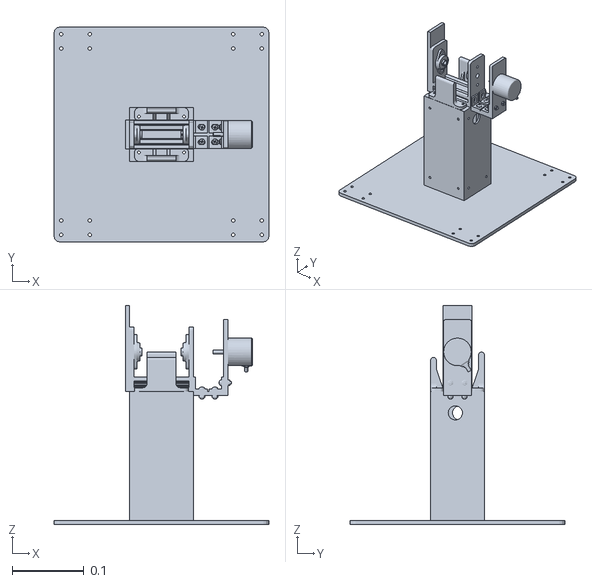
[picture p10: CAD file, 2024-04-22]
URDF file/2dofhover/meshes/base.STL
0.3 x 0.3 x 0.306

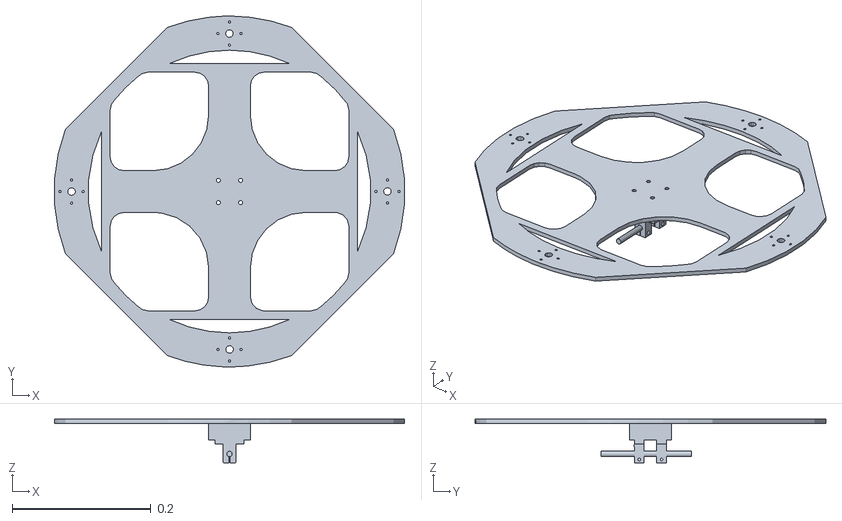
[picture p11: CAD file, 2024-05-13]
Website/control-chef-website/src/2dofhover/meshes/link2.STL
0.504 x 0.505 x 0.0628

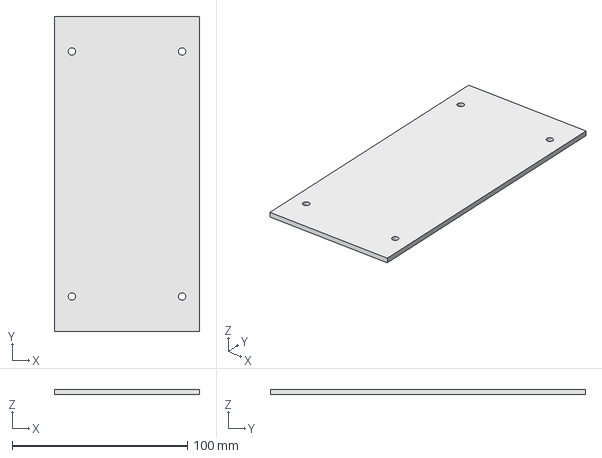
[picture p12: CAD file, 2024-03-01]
Model/Non Linear Model/BaseC_2_ipt_c71fdd73.STEP
83.0 x 180.0 x 3.00 mm

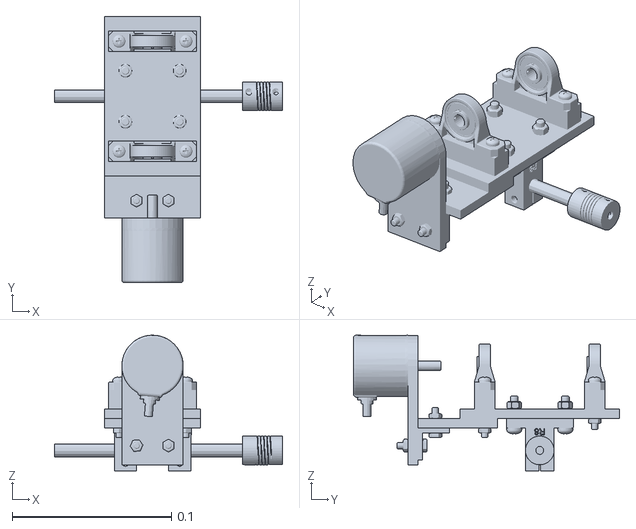
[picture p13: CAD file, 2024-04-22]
URDF file/2dofhover/meshes/j1.STL
0.143 x 0.167 x 0.085

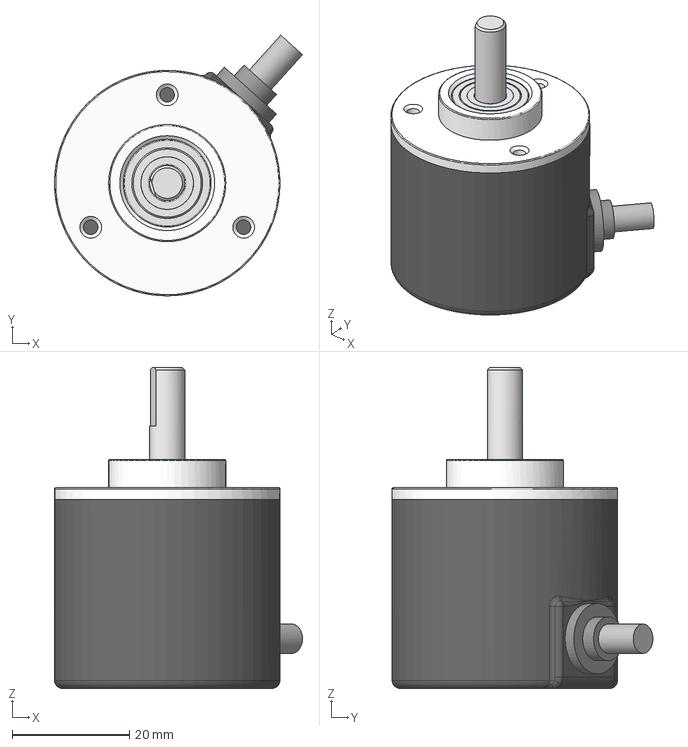
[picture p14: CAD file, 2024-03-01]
Model/Non Linear Model/Encoder_ipt_17a81f20.STEP
42.3 x 44.5 x 54.8 mm

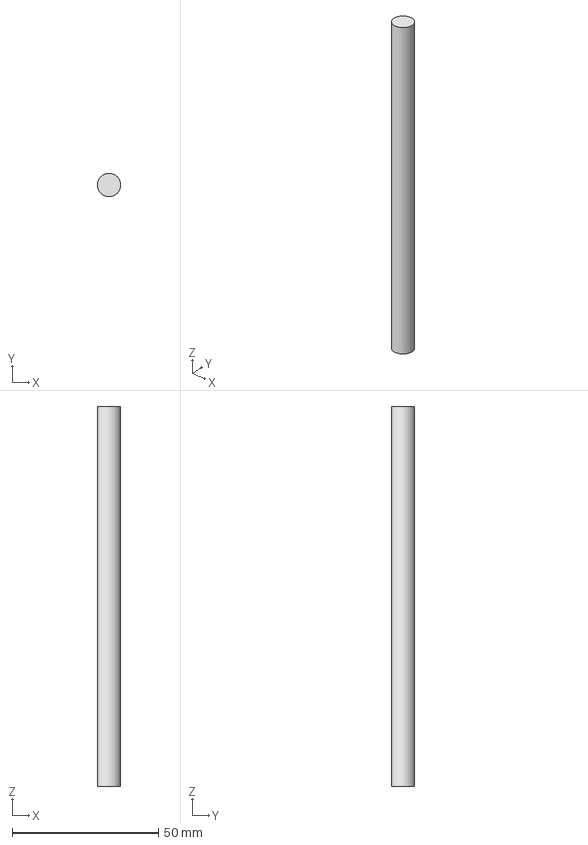
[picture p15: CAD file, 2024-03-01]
Model/Non Linear Model/shaft_ipt_d510e08f.STEP
7.99 x 8.00 x 130.0 mm

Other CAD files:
Codes/RVG_Test/RVG0_ert_rtw/ert_main.obj
CAD/Templates/English/ANSI (in).dwg
CAD/Templates/Metric/GOST.dwg
CAD/Templates/Standard.dwg
CAD/Templates/Metric/DIN.dwg
Codes/RVG_Test/RVG0_ert_rtw/RVG0.obj
CAD/Templates/Metric/JIS.dwg
CAD/Templates/Metric/ANSI (mm).dwg
CAD/Templates/Metric/GB.dwg
CAD/Design Data/AIT/Mold Design/mold design stop pin.ipt
CAD/Design Data/Cable & Harness/en-US/harness.iam
CAD/Design Data/Tube & Pipe/en-US/piping runs.iam
CAD/Templates/English/ANSI (in).idw
CAD/Templates/English/Mold Design (in).iam
CAD/Templates/English/Sheet Metal (in).ipt
CAD/Templates/English/Standard (in).iam
CAD/Templates/English/Standard (in).ipn
CAD/Templates/English/Standard (in).ipt
CAD/Templates/English/Weldment (ANSI).iam
CAD/Templates/Metric/ANSI (mm).idw
CAD/Templates/Metric/BSI.dwg
CAD/Templates/Metric/BSI.idw
CAD/Templates/Metric/DIN.idw
CAD/Templates/Metric/GB.idw
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

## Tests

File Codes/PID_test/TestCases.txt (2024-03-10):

Test1:
#define Kp 1
#define Ki 0
#define Kd 0
#define SP 5
#define MinSat -9999
#define MaxSat 9999

Test2:
#define Kp 1
#define Ki 1
#define Kd 0
#define SP 5
#define MinSat -9999
#define MaxSat 9999

*the resetPID function which was in the loop caused unexpected behaviour of resetting the prevTime PID parameter.

Test3:
#define Kp 1
#define Ki 1
#define Kd 0
#define SP 5
#define MinSat -9999
#define MaxSat 9999

*removed the resetPID function from the loop

Test4:
#define Kp 1
#define Ki 1
#define Kd 1
#define SP 5
#define MinSat -9999
#define MaxSat 9999

Test5:
#define Kp 50
#define Ki 35
#define Kd 22
#define SP 5
#define MinSat -9999
#define MaxSat 9999

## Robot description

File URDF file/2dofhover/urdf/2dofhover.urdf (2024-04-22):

<?xml version="1.0" encoding="utf-8"?>
<!-- This URDF was automatically created by SolidWorks to URDF Exporter! Originally created by Stephen Brawner (brawner@gmail.com) 
     Commit Version: 1.6.0-4-g7f85cfe  Build Version: 1.6.7995.38578
     For more information, please see http://wiki.ros.org/sw_urdf_exporter -->
<robot name="2dofhover">
  <link name="base">
    <inertial>
      <origin xyz="-0.016826 -0.080636 0.015707" rpy="0 0 0" />
      <mass value="1.0757" />
      <inertia ixx="0.0049592" ixy="1.0436E-07" ixz="6.6467E-08" iyy="0.0081937" iyz="-2.1759E-08" izz="0.0049846" />
    </inertial>
    <visual>
      <origin xyz="0 0 0" rpy="0 0 0" />
      <geometry>
        <mesh filename="package://2dofhover/meshes/base.STL" />
      </geometry>
      <material name="">
        <color rgba="0.74902 0.74902 0.74902 1" />
      </material>
    </visual>
    <collision>
      <origin xyz="0 0 0" rpy="0 0 0" />
      <geometry>
        <mesh filename="package://2dofhover/meshes/base.STL" />
      </geometry>
    </collision>
  </link>
  <link name="j1">
    <inertial>
      <origin xyz="-0.02174 -0.037566 0.028779" rpy="0 0 0" />
      <mass value="0.17488" />
      <inertia ixx="5.3586E-05" ixy="-1.1365E-08" ixz="-2.4314E-08" iyy="5.0819E-05" iyz="-2.0083E-07" izz="7.5605E-05" />
    </inertial>
    <visual>
      <origin xyz="0 0 0" rpy="0 0 0" />
      <geometry>
        <mesh filename="package://2dofhover/meshes/j1.STL" />
      </geometry>
      <material name="">
        <color rgba="0.7451 0.73725 0.72941 1" />
      </material>
    </visual>
    <collision>
      <origin xyz="0 0 0" rpy="0 0 0" />
      <geometry>
        <mesh filename="package://2dofhover/meshes/j1.STL" />
      </geometry>
    </collision>
  </link>
  <joint name="joint1" type="revolute">
    <origin xyz="0 -0.015857 0.082506" rpy="-0.0066031 0 0" />
    <parent link="base" />
    <child link="j1" />
    <axis xyz="1 0 0" />
    <limit lower="-0.5302" upper="0.517" effort="0" velocity="0" />
  </joint>
  <link name="j2">
    <inertial>
      <origin xyz="9.8601E-06 -0.0050154 0.067353" rpy="0 0 0" />
      <mass value="1.2356" />
      <inertia ixx="0.013051" ixy="-1.6066E-07" ixz="-8.5556E-08" iyy="0.013043" iyz="5.803E-08" izz="0.025474" />
    </inertial>
    <visual>
      <origin xyz="0 0 0" rpy="0 0 0" />
      <geometry>
        <mesh filename="package://2dofhover/meshes/j2.STL" />
      </geometry>
      <material name="">
        <color rgba="0.7451 0.73725 0.72941 1" />
      </material>
    </visual>
    <collision>
      <origin xyz="0 0 0" rpy="0 0 0" />
      <geometry>
        <mesh filename="package://2dofhover/meshes/j2.STL" />
      </geometry>
    </collision>
  </link>
  <joint name="joint2" type="revolute">
    <origin xyz="-0.023721 -0.00066717 0.052996" rpy="0 0.10915 3.1416" />
    <parent link="j1" />
    <child link="j2" />
    <axis xyz="0 1 0" />
    <limit lower="-0.68636" upper="0.4506" effort="0" velocity="0" />
  </joint>
</robot>

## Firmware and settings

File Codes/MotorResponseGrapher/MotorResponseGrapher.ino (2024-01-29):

/**
   Complete project details at https://RandomNerdTutorials.com/arduino-load-cell-hx711/

   HX711 library for Arduino - example file
   https://github.com/bogde/HX711

   MIT License
   (c) 2018 Bogdan Necula

**/

#include <Arduino.h>
#include "HX711.h"
#include <ESP32Servo.h>


Servo Fmotor, Rmotor, Bmotor, Lmotor;
int potValue;  // value from the analog pin
float maxload = 0;
void setup() {
  Serial.begin(115200);
  //Serial.println("HX711 Demo");
  //Serial.println("Initializing the scale");
  Fmotor.attach(26, 1000, 2000); // (pin, min pulse width, max pulse width in microseconds)
  Rmotor.attach(27, 1000, 2000);
  Bmotor.attach(16, 1000, 2000);
  Lmotor.attach(17, 1000, 2000);

  Fmotor.write(0); // (pin, min pulse width, max pulse width in microseconds)
  Rmotor.write(0);
  Bmotor.write(0);
  Lmotor.write(0);
  // scale.begin(LOADCELL_DOUT_PIN, LOADCELL_SCK_PIN);

  //Serial.println("Before setting up the scale:");
  //Serial.print("read: \t\t");
  //Serial.println(scale.read());      // print a raw reading from the ADC

  //Serial.print("read average: \t\t");
  //Serial.println(scale.read_average(20));   // print the average of 20 readings from the ADC

  //Serial.print("get value: \t\t");
  //Serial.println(scale.get_value(5));   // print the average of 5 readings from the ADC minus the tare weight (not set yet)

  //Serial.print("get units: \t\t");
  //Serial.println(scale.get_units(5), 1);  // print the average of 5 readings from the ADC minus tare weight (not set) divided
  // by the SCALE parameter (not set yet)

  //scale.set_scale(-370);
  //scale.set_scale(-471.497);                      // this value is obtained by calibrating the scale with known weights; see the README for details
  //scale.tare();               // reset the scale to 0
  //
  //  Serial.println("After setting up the scale:");
  //
  //  Serial.print("read: \t\t");
  //  Serial.println(scale.read());                 // print a raw reading from the ADC
  //
  //  Serial.print("read average: \t\t");
  //  Serial.println(scale.read_average(20));       // print the average of 20 readings from the ADC
  //
  //  Serial.print("get value: \t\t");
  //  Serial.println(scale.get_value(5));   // print the average of 5 readings from the ADC minus the tare weight, set with tare()
  //
  //  Serial.print("get units: \t\t");
  //  Serial.println(scale.get_units(5), 1);        // print the average of 5 readings from the ADC minus tare weight, divided
  //            // by the SCALE parameter set with set_scale

  //Serial.println("Readings:");
  Serial.print("Power,");
  Serial.println("Lift");
}

void loop() { //potValue = analogRead(A1);   // reads the value of the potentiometer (value between 0 and 1023)
  if (Serial.available()) {
    potValue = Serial.parseInt();
    Fmotor.writeMicroseconds(potValue);    // Send the signal to the Fmotor
    Rmotor.writeMicroseconds(potValue);    // Send the signal to the Fmotor
    Bmotor.writeMicroseconds(potValue);    // Send the signal to the Fmotor
    Lmotor.writeMicroseconds(potValue);
    delay(2000);
    for (int i = 0; i < 40; i++) {
      Fmotor.writeMicroseconds(potValue);    // Send the signal to the Fmotor
      Rmotor.writeMicroseconds(potValue);    // Send the signal to the Fmotor
      Bmotor.writeMicroseconds(potValue);    // Send the signal to the Fmotor
      Lmotor.writeMicroseconds(potValue);    // Send the signal to the Fmotor
    }
    Serial.read();
    potValue = Serial.parseInt();
    unsigned long st = millis();
    for (int i = 0; i < 160; i++) {
      st = millis();
      Fmotor.writeMicroseconds(potValue);    // Send the signal to the Fmotor
      Rmotor.writeMicroseconds(potValue);    // Send the signal to the Fmotor
      Bmotor.writeMicroseconds(potValue);    // Send the signal to the Fmotor
      Lmotor.writeMicroseconds(potValue);    // Send the signal to the Fmotor
    }
    potValue = 0;
    Fmotor.write(0); // (pin, min pulse width, max pulse width in microseconds)
    Rmotor.write(0);
    Bmotor.write(0);
    Lmotor.write(0);
    Serial.flush();
    while (Serial.available())Serial.read();
  }

}

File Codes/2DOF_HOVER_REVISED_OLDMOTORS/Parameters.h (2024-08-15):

/*
 * Header file with all the control parameters for the system
 * Credit: Scorpion
 * Created: 12/10/2023
 * Last update: 5/3/2024
 */
#pragma once

//#define OnlineControl
#define CascadedPIDControl
#include <ArduinoJson.h>
// Defines the wiring for each major component
#define X_ENCODER_PIN_A 32
#define X_ENCODER_PIN_B 33
#define Y_ENCODER_PIN_A 34
#define Y_ENCODER_PIN_B 35
#define FrontMotorPIN 17
#define RightMotorPIN 16
#define BackMotorPIN 27
#define LeftMotorPIN 26
#define PitchCurrentSense 36 
#define RollCurrentSense 39
#define ZERO_CURRENT_VOLTAGE 1.65 // Voltage at zero current
#define ACS712_SENSITIVITY 66 // mV per Amp for ACS712-30A
#define CutoffCurrent 20 //Amps
#define CutoffCurrentTime 5000
// IoT Parameters
#define ResetTime 60 //seconds without iot activity to reset after
#define Send_Period 300 // Unit is ms
unsigned long lastsent = 0,lastAquired;
#define SendingQoS 0
#define ReceiveQoS 0
#define SendingBufferSize 4096 // Adjust the size according to your needs
StaticJsonDocument<SendingBufferSize> SendingDoc; 
StaticJsonDocument<256> DataPacket;
StaticJsonDocument<512> ParamterObject;
char SendingString[SendingBufferSize];  // Adjust the size according to your needs
char WarnString[500];  // Adjust the size according to your needs
bool Readytosend = false;  // Send flag, set this to true when ready to send the buffer
// Rest in Secrets.h

int counta = 0;
int failcount = 0, failLimit = 200;
int failed_Trials = 0, fail_TrailLimit = 4;
int maxStartupSamples = 1000, RunSamples = 2000;


// Error corrections for IMU
#define IMU_XACC_Error  -0.02
#define IMU_YACC_Error   0.00
#define IMU_ZACC_Error  -0.03
#define IMU_XDOT_Error  1.14 * PI / 180
#define IMU_YDOT_Error  -1.87 * PI / 180
float xDotIMU, yDotIMU;
float AccX, AccY, AccZ;
float xPosIMU = 0;
float yPosIMU = 0;

// Main loop parameters
double xSpeed, ySpeed; // Feedback speeds for control (after Fusion)
unsigned int Sampling_time = 5000;
double IMU_FusionPrio = 0.02;
byte ControllerRunning = 1, ESC_Running = 1;
float xAction, yAction;
byte Work = 0;

// Parameters for PID control
float xposkp = 8;   // Proportional gain for X position
float xposki = 0.5; // Integral gain for X position
float xposkd = 0;   // Derivative gain for X position
float xvelkp = 15;  // Proportional gain for X velocity
float xvelki = 1;   // Integral gain for X velocity
float xvelkd = 0;   // Derivative gain for X velocity

float yposkp = 10;  // Proportional gain for Y position
float yposki = 0.5; // Integral gain for Y position
float yposkd = 0;   // Derivative gain for Y position
float yvelkp = 13;  // Proportional gain for Y velocity
float yvelki = 1;   // Integral gain for Y velocity
float yvelkd = 0;   // Derivative gain for Y velocity

float xposSet = 0;  // Setpoint for X position
float yposSet = 0;  // Setpoint for Y position
float xvelSet = 0;  // Setpoint for X velocity
float yvelSet = 0;  // Setpoint for Y velocity
float PositionLoopSat = 2; // Saturation limit for position loop

// Limits for PID parameters and setpoints
float xposkpLimit = 12;  // Limit for X position proportional gain
float xposkiLimit = 5;   // Limit for X position integral gain
float xposkdLimit = 5;   // Limit for X position derivative gain
float xvelkpLimit = 30;  // Limit for X velocity proportional gain
float xvelkiLimit = 5;   // Limit for X velocity integral gain
float xvelkdLimit = 5;   // Limit for X velocity derivative gain

float yposkpLimit = 10;  // Limit for Y position proportional gain
float yposkiLimit = 5;   // Limit for Y position integral gain
float yposkdLimit = 5;   // Limit for Y position derivative gain
float yvelkpLimit = 20;  // Limit for Y velocity proportional gain
float yvelkiLimit = 5;   // Limit for Y velocity integral gain
float yvelkdLimit = 5;   // Limit for Y velocity derivative gain

float xposSetLimit = 0.3; // Limit for X position setpoint
float yposSetLimit = 0.3; // Limit for Y position setpoint

// Parameters for ESCs and motors
#define xmaxMicros 1700
#define xminMicros 1100
#define xmaxDeltaMicros 300
#define xmaxDeltaMicrosStart 400
int xOpratingpoint = 1400;

#define ymaxMicros 1700
#define yminMicros 1100
#define ymaxDeltaMicros 300
#define ymaxDeltaMicrosStart 350
int yOpratingpoint = 1400;

// Encoder Parameters
#define PPR 8000   // Counts per revolution for encoders (PPR*4)
#define pre 20     // Prescaler for hardware timers
#define NoP  8     // Number of counts for rolling average for encoder velocity calculation
unsigned long lastMqttMessageTime;
volatile long xEncoderCount = 0, yEncoderCount = 0;
unsigned long xLastSpeedTime, yLastSpeedTime;
uint64_t SpeedUpdateTime = 20000;
hw_timer_t *SpeedUpdateTimer = NULL, *IntTimer = NULL;
volatile int64_t xNext = 0, yNext = 0;
volatile double xDelta[NoP], yDelta[NoP];

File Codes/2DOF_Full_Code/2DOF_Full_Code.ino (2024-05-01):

#include <WiFi.h>
#include <EEPROM.h>
#include <ESP32Servo.h>
#include "Secrets.h"
#include "Parameters.h"
#include "RVG0.h"
#include "IMU.h"
#include "encoder.h"
#include "PID.h"
#include "motors.h"
#include "StartUP.h"
#include "commonFunctions.h"
#include "OTA.h"
#include "AWS_IOT.h"
//#define OFFLINE
TaskHandle_t TaskHandle_1;

void setup() {
  Serial.begin(115200);//init Serial For debugging
  //initEncoder(0, 0);
  //Over the air task to allow wireless flash runs on core 1
#ifndef OFFLINE
  initWIFI();// Blocking Stop for offline

  xTaskCreatePinnedToCore(
    OTATASK,
    "OTA Routine",
    5000,
    NULL,
    0,
    NULL,
    1);

  //Data Acquisition  Task Run on core 0 for now
  xTaskCreatePinnedToCore(
    DataAQU,   // Function to implement the task
    "Data AQU Loop", // Name of the task
    5000,      // Stack size in words
    NULL,       // Task input parameter
    0,          // Priority of the task
    NULL,       // Task handle.
    0);  // Core where the task should run
#endif
  //Main Loop task runs on core 0
  xTaskCreatePinnedToCore(
    PIDLoop,   //Function to implement the task
    "Main Loop", // Name of the task
    10000,      // Stack size in words
    NULL,       // Task input parameter
    9,          // Priority of the task
    &TaskHandle_1,       // Task handle.
    0);  // Core where the task should run


}
//#define DebugCFMain
void loop() {

  //if debug then print the values between IMU and Encoder
#ifdef DebugCFMain
  updateIMU();
  //  Serial.print(xVELPID.setpoint);
  //  Serial.print(", ");
  //  Serial.print(xSpeed);
  //  Serial.print(", ");
  //  Serial.print(xVELPID.integral);
  //  Serial.print(", ");
  //  Serial.println(xVELPID.output - xVELPID.integral);
  //  Serial.print("XPOS:");
  //  Serial.print(xPOSPID.setpoint);
  //  Serial.print(", ");
  Serial.print(CountsToAngle(xEncoderCount));
  Serial.print(", ");
  Serial.print(CountsToAngle(yEncoderCount));
  Serial.print(", ");
  Serial.print(xPosIMU);
  Serial.print(", ");
  Serial.println(yPosIMU);

  //  Serial.print(xPOSPID.integral);
  //  Serial.print(", ");
  //  Serial.println(xPOSPID.output);
  vTaskDelay(50 / portTICK_PERIOD_MS);
#endif
}

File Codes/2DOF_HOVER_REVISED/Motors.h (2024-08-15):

/*
   Submodule that contains all the brushless motor functions
   Credit: Scorpion
   Created: 14/11/2023
*/
#include <ESP32Servo.h>
#include "Parameters.h"

#pragma once

class ESP32ESC
{
private:
  // Hardware attributes
  byte oPin; // ESC output Pin

  // Calibration values
  int oMin = 1000;                  // Minimum pulse width for ESC
  int oMax = 2000;                  // Maximum pulse width for ESC
  int oESC = 1000;                  // Current ESC pulse width
  int oArm = 1000;                   // Arm pulse width
  uint32_t calibrationDelay = 5000; // Calibration delay in milliseconds
  uint32_t stopPulse = 1000;        // Stop pulse duration in microseconds
  Servo myESC;                      // Servo object to control an ESC

public:
  // Constructor to initialize ESC pin and optional calibration parameters
  ESP32ESC(byte ESC_pin, int outputMin = 1000, int outputMax = 2000, int armVal = 1000)
  {
    oPin = ESC_pin;
    oMin = outputMin;
    oMax = outputMax;
    oArm = armVal;
  }

  // Destructor (empty as there's no dynamic memory allocation)
  ~ESP32ESC()
  {
    // Nothing to destruct
  }

  // Attach ESC to pin for operation
  void attach()
  {
    myESC.attach(oPin);
  }

  // Perform ESC calibration
  void calib()
  {
    myESC.attach(oPin);            // Attach ESC to the specified pin
    myESC.writeMicroseconds(oMax); // Send maximum signal to calibrate high
    delay(calibrationDelay);       // Wait for calibration
    myESC.writeMicroseconds(oMin); // Send minimum signal to calibrate low
    delay(calibrationDelay);       // Wait for calibration
    arm();                         // Arm the ESC after calibration
  }

  // Arm the ESC with pre-defined arm value
  void arm()
  {
    myESC.attach(oPin);            // Attach ESC to the specified pin
  }

  // Detach the ESC to stop signal transmission
  void detach()
  {
    myESC.writeMicroseconds(stopPulse); // Send stop pulse
    myESC.detach();                     // Detach ESC
  }

  // Stop the ESC by sending stop pulse
  void stop()
  {
    myESC.writeMicroseconds(stopPulse); // Send stop pulse
  }

  // Set ESC speed within calibrated range
  void speed(int outputESC)
  {
    oESC = constrain(outputESC, oMin, oMax); // Constrain speed within calibrated limits
    myESC.writeMicroseconds(oESC);           // Set ESC speed
  }

  // Set the calibration delay
  void setCalibrationDelay(uint32_t calibration_delay)
  {
    calibrationDelay = calibration_delay; // Set calibration delay
  }

  // Set the stop pulse duration
  void setStopPulse(uint32_t stop_pulse)
  {
    stopPulse = stop_pulse; // Set stop pulse duration
  }
};

// Instantiate four motors using ESP32ESC class with defined pins
ESP32ESC Fmotor(FrontMotorPIN), Rmotor(RightMotorPIN), Bmotor(BackMotorPIN), Lmotor(LeftMotorPIN);

// Calibrate all ESCs at startup
void calibESCs()
{
  // Attach all motors and set maximum signal for calibration
  Fmotor.attach(); Rmotor.attach(); Bmotor.attach(); Lmotor.attach();
  Fmotor.speed(2000); Rmotor.speed(2000); Bmotor.speed(2000); Lmotor.speed(2000);
  
  // Wait for calibration (first delay)
  delay(6000);

  // Set minimum signal for calibration
  Fmotor.speed(1000); Rmotor.speed(1000); Bmotor.speed(1000); Lmotor.speed(1000);

  // Wait for calibration (second delay)
  delay(6000);

  // Arm all ESCs after calibration
  Fmotor.arm(); Rmotor.arm(); Bmotor.arm(); Lmotor.arm();
}


// Initialize ESCs, arm them, and gradually start up
void initESCs()
{
  Fmotor.arm(); // Arm Front motor
  Rmotor.arm(); // Arm Right motor
  Bmotor.arm(); // Arm Back motor
  Lmotor.arm(); // Arm Left motor

  // Gradually increase speed to start motors smoothly
  for (unsigned int i = 1000; i < 1100; i += 5)
  {
    Fmotor.speed(i); // Set Front motor speed
    Rmotor.speed(i); // Set Right motor speed
    Bmotor.speed(i); // Set Back motor speed
    Lmotor.speed(i); // Set Left motor speed
    delay(10);       // Small delay between speed increments
  }
  delay(200);      // Additional delay after startup
  ESC_Running = 1; // Set ESC running flag
}

// Disable all motors by stopping and detaching them
void DisableMotors()
{
  Fmotor.stop();   // Stop Front motor
  Rmotor.stop();   // Stop Right motor
  Bmotor.stop();   // Stop Back motor
  Lmotor.stop();   // Stop Left motor
  Fmotor.detach(); // Detach Front motor
  Rmotor.detach(); // Detach Right motor
  Bmotor.detach(); // Detach Back motor
  Lmotor.detach(); // Detach Left motor
}

// Write speed values to all ESCs if running flag is set
void writeSpeed(uint32_t Fmicros, uint32_t Rmicros, uint32_t Bmicros, uint32_t Lmicros)
{
  if (ESC_Running == 1)
  {
    Fmotor.speed(Fmicros); // Set Front motor speed
    Rmotor.speed(Rmicros); // Set Right motor speed
    Bmotor.speed(Bmicros); // Set Back motor speed
    Lmotor.speed(Lmicros); // Set Left motor speed
  }
  else
  {
    DisableMotors(); // Disable motors if running flag is not set
  }
}

// Write control actions (delta values) to adjust motor speeds
void writeControlAction(int xAct, int yAct)
{
  // Calculate adjusted motor speeds based on control actions and operating points
  uint32_t FM = min(max(yOpratingpoint + yAct, yminMicros), ymaxMicros); // Front motor speed
  uint32_t RM = min(max(xOpratingpoint + xAct, xminMicros), xmaxMicros); // Right motor speed
  uint32_t BM = min(max(yOpratingpoint - yAct, yminMicros), ymaxMicros); // Back motor speed
  uint32_t LM = min(max(xOpratingpoint - xAct, xminMicros), xmaxMicros); // Left motor speed

  // Write adjusted speeds to motors
  writeSpeed(FM, RM, BM, LM);

#ifdef DebugMotor
  // Debugging: Print motor power levels
  Serial.println((String) "POWERS: " + FM + ", " + RM + ", " + BM + ", " + LM);
#endif
}
float readCurrent(int analogPin) {
    const int NUM_SAMPLES = 100; // Number of samples to average
    long sum = 0;

    for (int i = 0; i < NUM_SAMPLES; i++) {
        sum += analogRead(analogPin);
    }

    float average = sum / NUM_SAMPLES;

    // Convert the analog reading to voltage
    float voltage = (average * 3.3) / 4096.0;

    // Calculate the current
    float current = (voltage - ZERO_CURRENT_VOLTAGE) / (ACS712_SENSITIVITY / 1000.0);

    return current;
}

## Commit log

2023-12-18 Initial Publish
    Tested IMU, OTA
2023-12-18 Added Structure
    Add folders for cad and wiring
2024-01-25 Finalized Untested Code
    #Modified the encoder code to work faster at 5ms sampling time.
    #Modified the PID code to run correctly
    #added the Data Acquisition task
    #Modfied The IMU function to be more straight forward
    #changed the pre-scaler to 20
    #added a windup controller
    [2DOF_Full_Code.ino, IMU.h, Parameters.h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]
2024-03-01 Added model folder to host all the simulations.
    added place holder to host most of the files.
    [2020RightAngle.ipt, 2020RightAngle_ipt_a59fb1f2.STEP, 20x20mm V-Slot.ipt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]
2024-03-02 added data files
    [Encoder Stability test.xlsx, Encoder test with N=1.xlsx]
2024-03-02 Create Encoder damping.xlsx
    [Encoder damping.xlsx]
2024-03-05 Edited the cad
    Added The new guards
    Adjusted Inertias
    [9. Fan.0005.ipt, 9. Fan.ipt, Assembly1.0012.iam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]
2024-03-05 Added code to test PID
2024-03-10 Added Inertial Folder with both joint inertias
2024-03-10 TestPID updated and fixed pid errors
2024-03-10 Getting Inertias and CG from cad in Inertias folder
    [AssemblyVero.0016.iam, AssemblyVero.0018.iam, AssemblyVero.iam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]
2024-03-10 Lots of added changes
    added screenshots for arm lengths, created motor estimation preliminary code, motor estimation preliminary model
2024-03-17 Added The Code and data from MQTT delay test
    [MQTT_Delay_Test2024-03-17 18-24.xlsx, MQTT_Delay_Test2024-03-17 19-03.xlsx]
2024-03-18 Getting Data
    [Data.xlsx]
2024-03-19 Lab work
    [Data.xlsx, DataV2.xlsx]
2024-03-19 Estimation model updated
    Inertia and mass need to be updated asap
    [Estimation_M_Front.xlsx]
2024-03-20 Updated Cad Weights, Updated Inertia screenshots Folder
    [9. Fan.0005.ipt, 9. Fan.0006.ipt, 9. Fan.ipt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]
2024-03-20 Huge changes with the doctor
    [15 to 60 backmotor.xlsx, 3DOF PCB.ipt, Estimation_M_Back.xlsx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]
2024-03-20 added old version for motor estimation model
2024-03-25 RVG test code
    [RVG0.obj, ert_main.obj]
2024-03-26 Abdo and dr changes in pid
2024-03-27 Revert "Abdo and dr changes in pid"
    This reverts commit 74343ff426763964093e33d3620fa5a6d2fa9309.
    [2DOF_Full_Code.ino, PID.h, Parameters.h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]
2024-03-27 Revert "Revert "Abdo and dr changes in pid""
    This reverts commit 42272d5d4d1e1cc649a5f9b0196110fd65ef3846.
    [2DOF_Full_Code.ino, PID.h, Parameters.h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]
2024-04-22 Major Quality of life changes
    * Added the ability to switch on and off remotely
    * Added the detection of faulty parameters and switching to swing up when needed
    * Made the IOT message dynamic so only changed parameters need to be sent
    * Changed Variable Names to be more apparent
    * Ensured that the system reboots after a parameter change correctly
    * changed operating point to be safer and less noisy
    * Added limits over the parameters
    * made the swing up semi tunable by making them a function of the normal parameters (3 * the normal parameters)
    * changed the switching from swing up to normal mode to be based on both angular velocity and position
    [2DOF_Full_Code.ino, Parameters.h, StartUP.h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]
2024-04-22 URDF by Tarek
    YAaallllooo
    [2dofhover.csv, 2dofhover.urdf, base.STL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]
2024-04-23 Protected ESCs against calibration routine
2024-06-03 added new urdf
    [2dofhover.urdf, sss.urdf]
2024-06-19 Fixed Generated model issues
    [TwoDOF.c, TwoDOF.h]
2024-06-20 2DOF_SL updated
    [partitions.csv]
2024-06-26 final Changes
    [partitions.csv]
2024-07-17 Revised The Main Code
    Features:
    -Switched from pubSubClient to espMqttClient for QoS support
    -better memory management and added security against leaks
    -Switched to a dedicated ESC class that handles any communication with the motors (to be tested vigorously)
    -
    [CascadedPID.h, IMU.h, Motors.h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]
2024-08-15 Added New Hardware Code
    [partitions.csv]
2024-08-22 Motors Working
2024-08-22 added old support for motors
